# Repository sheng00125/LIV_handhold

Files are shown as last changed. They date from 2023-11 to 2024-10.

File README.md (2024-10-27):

# [LiDAR_Inertial_Visual_Handhold](https://zhuanlan.zhihu.com/p/670136001)

### News
* **`27 October 2024`:** Add modified livox_ros_driver2 with time sync support for Mid360.
* **`11 October 2024`:** Add support for other pixel formats besides RGB8 (e.g., BayerRG8, BayerRG12Packed).
* **`03 October 2024`:** Add ARM support, fix the camera driver startup and shutdown bug, remove the SerialNumber dependency, resolve the auto-exposure mode switching issue, and add a TriggerEnable interface to allow testing the camera without the PPS signal.
* **`15 July 2024`:** Fix the bug related to LiDAR (IMU) timestamp compensation in the `livox_ros_driver`, remove the dynamic library dependency from `mvs_ros_driver`, and enable this synchronization scheme to use the official `livox_sdk`.
* **`28 June 2024`:** Update reproduction videos and some important notes.
* **`27 May 2024`:** Fix a bug in the calculation of the synthetic GPRMC timestamp, which could cause timestamp rollback. Additionally, we add checksum verification for GPRMC.
* **`20 May 2024`:** According to Livox Avia's pin requirements, we convert PPS TTL level to RS485 level and supplement it with more detailed electronic connection and material list.

## 1. Introduction
This repository provides the **CAD files** (with suffix “\*.SLDPRT and \*.SLDASM”) for our handheld device, which can be opened and edited with [*Solidworks*](https://www.solidworks.com). All of the modules are suitable for printing with [*FDM (Fused Deposition Modeling)*](https://en.wikipedia.org/wiki/Fused_filament_fabrication). In addition, we have also open-sourced our **hardware synchronization scheme**, as well as the **STM32 source code** and **hardware wiring configuration** instructions.

<div align="center">
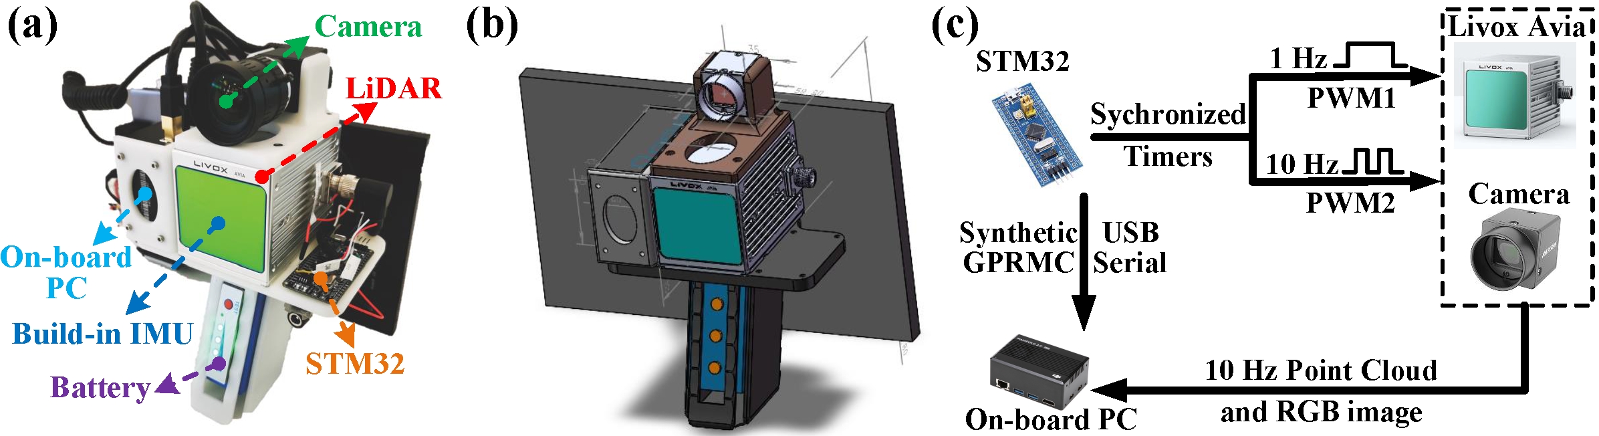
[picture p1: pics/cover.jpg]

</div>

## 2. Relevant guidance video 

Thanks to the Bilibili uploader [GundaSmart](https://space.bilibili.com/687639149?spm_id_from=333.788.0.0) for making a detailed reproduction video. Everyone can follow the video to reproduce it. His sensor configuration includes a MID360 and a Hikvision pinhole camera.

[FAST-LIVO Reproduction (Part 1)](https://www.bilibili.com/video/BV1T142197ci/?share_source=copy_web&vd_source=f77407286e8f0ee71b845d76498ada9d)

[FAST-LIVO Reproduction (Part 2)](https://www.bilibili.com/video/BV14T421X7m9/?share_source=copy_web&vd_source=f77407286e8f0ee71b845d76498ada9d)

[FAST-LIVO Reproduction (Part 3)](https://www.bilibili.com/video/BV16E42137ru/?share_source=copy_web&vd_source=f77407286e8f0ee71b845d76498ada9d)

[FAST-LIVO Reproduction (Part 4)](https://www.bilibili.com/video/BV1Yb421i7xK/?share_source=copy_web&vd_source=f77407286e8f0ee71b845d76498ada9d)

[FAST-LIVO Reproduction (Part 5)](https://www.bilibili.com/video/BV1Jz421b7px/?share_source=copy_web&vd_source=f77407286e8f0ee71b845d76498ada9d)

## 3. Guide to installation
### 3.1 Root directory

    ├── handhold_cad/ - CAD source files
    │   ├── ...
    ├── livox_ros_driver/ - Livox LiDAR ROS driver
    │   ├── ...
    ├── mvs_ros_pkg/ - Camera driver
    │   ├── ...
    └── stm32_timersync-open/ - Embedded engineering folder
    │   ├── USER/ - Main functionality folder
    │   ├── ...
    └── README.md - Project homepage document
    └── ...

### 3.2 Assembly instruction

The assembly instructions are demonstrated in the GIFs below. Each module is clearly labeled corresponding to the name of its STL file.

<p align="center">
  
  
</p>

### 3.3 Electronic connection
The guide for the electronic connections is presented as follows:

<table>
  <tr>
    <th>Livox AVIA LiDAR M12</th>
    <th>Peripheral Function</th>
    <th>Diagram</th>
  </tr>
  <tr>
    <td>PIN 1</td>
    <td>Power: +</td>
    <td rowspan="8" align="center">
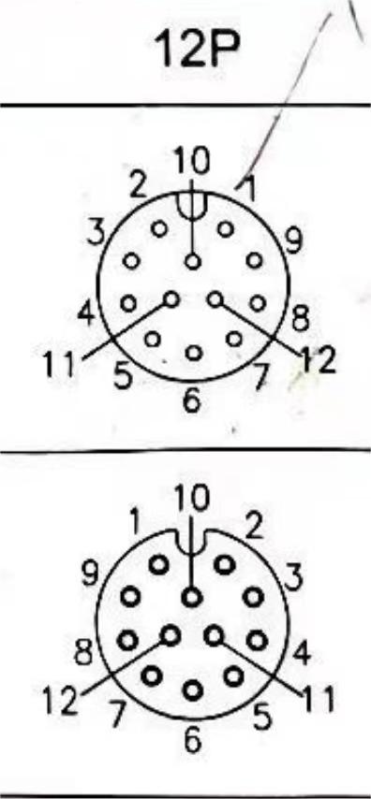
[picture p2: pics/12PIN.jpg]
      <br>
      <span style="display: block; text-align: center;">AVIA 12-Pin Interface, top: female bottom: male</span>
    </td>
  </tr>
  <tr>
    <td>PIN 2</td>
    <td>Ground</td>
  </tr>
  <tr>
    <td>PIN 7</td>
    <td>Ethernet: RX-</td>
  </tr>
  <tr>
    <td>PIN 6</td>
    <td>Ethernet: RX+</td>
  </tr>
  <tr>
    <td>PIN 5</td>
    <td>Ethernet: TX-</td>
  </tr>
  <tr>
    <td>PIN 4</td>
    <td>Ethernet: TX+</td>
  </tr>
  <tr>
    <td>PIN 11 (Sync-)</td>
    <td>RS485_Output B-</td>
  </tr>
  <tr>
    <td>PIN 12 (Sync+)</td>
    <td>RS485_Output A+</td>
  </tr>
</table>

<table>
  <tr>
    <th>MVS Camera 6PIN</th>
    <th>Name</th>
    <th>I/O Type</th>
    <th>Description</th>
    <th>Peripheral Function</th>
    <th>Diagram</th>
  </tr>
  <tr>
    <td>PIN 1</td>
    <td>DC_PWR</td>
    <td>--</td>
    <td>Power Supply</td>
    <td></td>
    <td rowspan="8" style="text-align: center;">
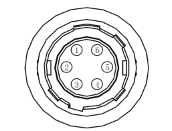
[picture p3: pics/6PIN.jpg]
      <br>
      <span style="display: block; text-align: center;">MVS Camera 6-Pin Interface</span>
    </td>
  </tr>
  <tr>
    <td>PIN 2</td>
    <td>OPTO_IN</td>
    <td>Line 0+</td>
    <td>Optical Isolation Input</td>
    <td>STM32 PA1</td>
  </tr>
  <tr>
    <td>PIN 3</td>
    <td>GPIO</td>
    <td>Line 2+</td>
    <td>General Purpose Input/Output</td>
    <td></td>
  </tr>
  <tr>
    <td>PIN 4</td>
    <td>OPTO_OUT</td>
    <td>Line 1+</td>
    <td>Optical Isolation Output</td>
    <td></td>
  </tr>
  <tr>
    <td>PIN 5</td>
    <td>OPTO_GND</td>
    <td>Line 0- / 1-</td>
    <td>Optical Isolation Ground</td>
    <td>STM32 GND</td>
  </tr>
  <tr>
    <td>PIN 6</td>
    <td>GND</td>
    <td>Line 2-</td>
    <td>Ground</td>
    <td></td>
  </tr>
</table>
<table>
  <tr>
    <th>STM32</th>
    <th>Peripheral Function</th>
  </tr>
  <tr>
    <td>PA1</td>
    <td>MVS camera PIN2 (OPTO_IN)</td>
  </tr>
  <tr>
    <td>PB5</td>
    <td>RS485_Input (TXD)</td>
  </tr>
  <tr>
    <td>PA9</td>
    <td>TTL2USB (RXD)</td>
  </tr>
  <tr>
    <td>VCC</td>
    <td>RS485_Input (VCC) | TTL2USB (VCC)</td>
  </tr>
  <tr>
    <td>GND</td>
    <td>RS485_Input (GND) | TTL2USB (GND) | MVS camera PIN5 (GND)</td>
  </tr>
</table>

<table>
  <tr>
    <th>RS485</th>
    <th>Peripheral Function</th>
  </tr>
  <tr>
    <td>RS485_Output A+</td>
    <td>LiDAR M12 PIN12 (Sync+)</td>
  </tr>
  <tr>
    <td>RS485_Output B-</td>
    <td>LiDAR M12 PIN11 (Sync-)</td>
  </tr>
  <tr>
    <td>RS485_Output (GND)</td>
    <td>LiDAR M12 PIN2 (GND)</td>
  </tr>
</table>

**🔴🔥 IMPORTANT:**
* **STM32 PB5 (PPS signal) is converted from TTL to RS-485, resulting in RS485_Output A+ and RS485_Output B-;**
* **STM32 TXD (GPRMC) is converted from TTL to USB and sent to the PC;** 
* **If you are using the Mid360, you can directly connect STM32 PB5 to LiDAR M12 pps interface;**
* **Before you `roslaunch livox_ros_driver livox_lidar_msg.launch`, you can use `sudo chmod a+rw /dev/ttyUSB0` grant permissions to the USB serial port;**
* **The default connection method in this repository directly connects to M12 without using the Livox converter. If you use the converter, you can connect STM32 PB5 (PPS signal) to the Livox converter Sync Port without converting TTL to 485 level. Refer to [Issue 19](https://github.com/sheng00125/LIV_handhold/issues/19) for details.**

## 4. How to run the driver
```bash
roslaunch mvs_ros_pkg mvs_camera_trigger.launch
roslaunch livox_ros_driver livox_lidar_msg.launch
rosbag record /livox/lidar /livox/imu left_camera/image
```

## 5. Main material lists (only for reference)
| Item  | Pics  | Purchasing list  |
| :---: | :---: | :---: |
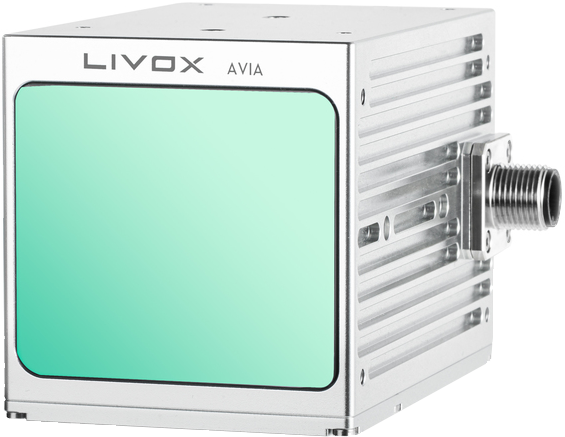
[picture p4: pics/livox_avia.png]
| Livox Avia LiDAR  |  | [Livox Avia](https://store.dji.com/hk-en/product/livox-avia) |
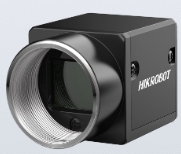
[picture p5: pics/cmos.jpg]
| CMOS |  | [MV-CA013-21UC ](https://www.hikrobotics.com/en/machinevision/productdetail?id=1314&pageNumber=1&pageSize=50) |
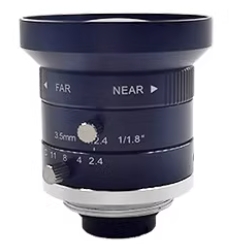
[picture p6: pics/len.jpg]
| Camera Len |  | [ MVL-HF0628M-6MPE](https://m.tb.cn/h.gXmtLRX2UYzGDzH?tk=hIS7WGPOY0y) |
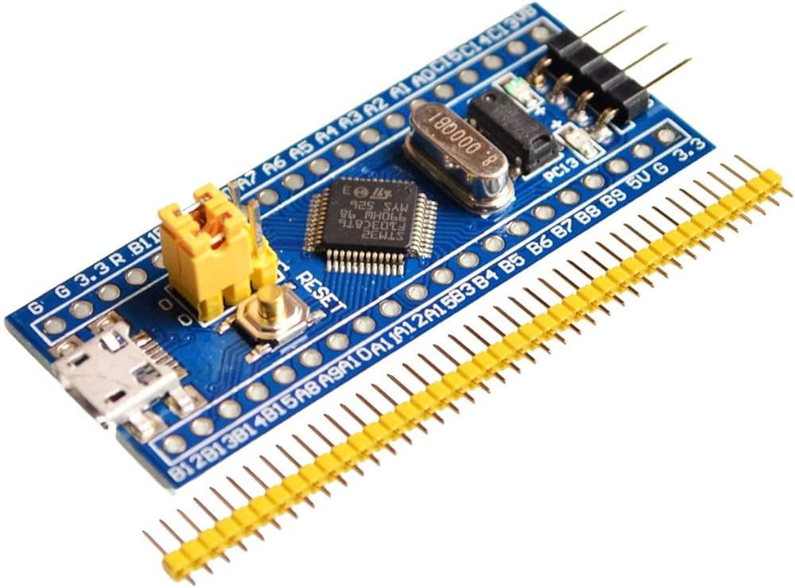
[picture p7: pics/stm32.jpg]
| STM32 |  | [STM32F103C8T6](https://m.tb.cn/h.ggkS9Kp?tk=orRfWz6M784) |
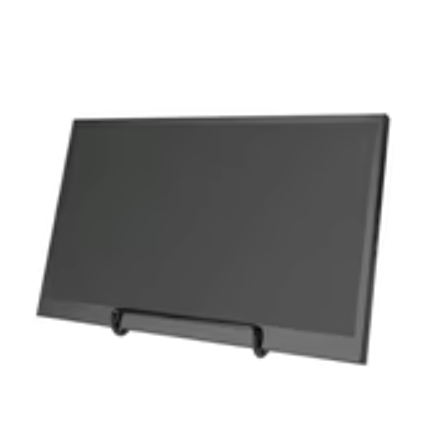
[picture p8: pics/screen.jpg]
| Screen |  | [IPS Screen 10''](https://m.tb.cn/h.ggkhQ7e?tk=LntBWz6mHDL) |
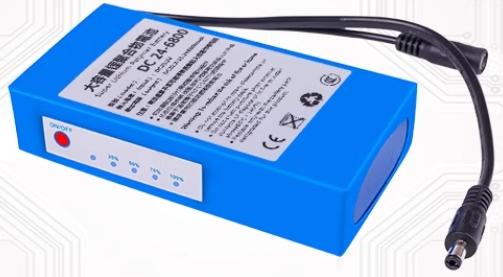
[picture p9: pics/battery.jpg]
| Battery |  | [4800mah](https://m.tb.cn/h.g5vJI7a?tk=ofKdWz6OYQm) |
| TTL to USB |  | [TTL to USB](https://m.tb.cn/h.gWzMxzBSkhSqkH3?tk=N1j3WEzIP9u) |
| TTL to 485 |  | [TTL to 485](https://m.tb.cn/h.g3SEkso?tk=eER4WEzFYmP) |

## 6. License
The source code is released under [GPLv3](http://www.gnu.org/licenses/) license. 

If you use any code of this repo in your academic research, it will be **very appreciated** if you can cite any of our following papers:

```
[1] Zheng, Chunran, et al. "FAST-LIVO2: Fast, Direct LiDAR-Inertial-Visual Odometry." 
[2] Zheng, Chunran, et al. "FAST-LIVO: Fast and Tightly-coupled Sparse-Direct LiDAR-Inertial-Visual Odometry." 
[3] Hong, Sheng, et al. "Rollvox: real-time and high-quality LiDAR colorization with rolling shutter camera." 
```

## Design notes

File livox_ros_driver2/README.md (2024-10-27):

# Update

Added the time synchronization function

# Livox ROS Driver 2

Livox ROS Driver 2 is the 2nd-generation driver package used to connect LiDAR products produced by Livox, applicable for ROS (noetic recommended) and ROS2 (foxy or humble recommended).

  **Note :**

  As a debugging tool, Livox ROS Driver is not recommended for mass production but limited to test scenarios. You should optimize the code based on the original source to meet your various needs.

## 1. Preparation

### 1.1 OS requirements

  * Ubuntu 18.04 for ROS Melodic;
  * Ubuntu 20.04 for ROS Noetic and ROS2 Foxy;
  * Ubuntu 22.04 for ROS2 Humble;

  **Tips:**

  Colcon is a build tool used in ROS2.

  How to install colcon: [Colcon installation instructions](https://docs.ros.org/en/foxy/Tutorials/Beginner-Client-Libraries/Colcon-Tutorial.html)

### 1.2 Install ROS & ROS2

For ROS Melodic installation, please refer to:
[ROS Melodic installation instructions](https://wiki.ros.org/melodic/Installation)

For ROS Noetic installation, please refer to:
[ROS Noetic installation instructions](https://wiki.ros.org/noetic/Installation)

For ROS2 Foxy installation, please refer to:
[ROS Foxy installation instructions](https://docs.ros.org/en/foxy/Installation/Ubuntu-Install-Debians.html)

For ROS2 Humble installation, please refer to:
[ROS Humble installation instructions](https://docs.ros.org/en/humble/Installation/Ubuntu-Install-Debians.html)

Desktop-Full installation is recommend.

## 2. Build & Run Livox ROS Driver 2

### 2.1 Clone Livox ROS Driver 2 source code:

```shell
git clone https://github.com/Livox-SDK/livox_ros_driver2.git ws_livox/src/livox_ros_driver2
```

  **Note :**

  Be sure to clone the source code in a '[work_space]/src/' folder (as shown above), otherwise compilation errors will occur due to the compilation tool restriction.

### 2.2 Build & install the Livox-SDK2

  **Note :**

  Please follow the guidance of installation in the [Livox-SDK2/README.md](https://github.com/Livox-SDK/Livox-SDK2/blob/master/README.md)

### 2.3 Build the Livox ROS Driver 2:

#### For ROS (take Noetic as an example):
```shell
source /opt/ros/noetic/setup.sh
./build.sh ROS1
```

#### For ROS2 Foxy:
```shell
source /opt/ros/foxy/setup.sh
./build.sh ROS2
```

#### For ROS2 Humble:
```shell
source /opt/ros/humble/setup.sh
./build.sh humble
```

### 2.4 Run Livox ROS Driver 2:

#### For ROS:

```shell
source ../../devel/setup.sh
roslaunch livox_ros_driver2 [launch file]
```

in which,  

* **livox_ros_driver2** : is the ROS package name of Livox ROS Driver 2;
* **[launch file]** : is the ROS launch file you want to use; the 'launch_ROS1' folder contains several launch samples for your reference;  

An rviz launch example for HAP LiDAR would be:

```shell
roslaunch livox_ros_driver2 rviz_HAP.launch
```

#### For ROS2:
```shell
source ../../install/setup.sh
ros2 launch livox_ros_driver2 [launch file]
```

in which,  

* **[launch file]** : is the ROS2 launch file you want to use; the 'launch_ROS2' folder contains several launch samples for your reference.

A rviz launch example for HAP LiDAR would be:

```shell
ros2 launch livox_ros_driver2 rviz_HAP_launch.py
```

## 3. Launch file and livox_ros_driver2 internal parameter configuration instructions

### 3.1 Launch file configuration instructions

Launch files of ROS are in the "ws_livox/src/livox_ros_driver2/launch_ROS1" directory and launch files of ROS2 are in the "ws_livox/src/livox_ros_driver2/launch_ROS2" directory. Different launch files have different configuration parameter values and are used in different scenarios:

| launch file name | Description |
| --- | --- |
| rviz_HAP.launch | Connect to HAP LiDAR device<br>Publish pointcloud2 format  data<br>Autoload rviz |
| msg_HAP.launch | Connect to HAP LiDAR device<br>Publish livox customized pointcloud data|
| rviz_MID360.launch | Connect to MID360 LiDAR device<br>Publish pointcloud2 format data <br>Autoload rviz|
| msg_MID360.launch | Connect to MID360 LiDAR device<br>Publish livox customized pointcloud data |
| rviz_mixed.launch | Connect to HAP and MID360 LiDAR device<br>Publish pointcloud2 format data <br>Autoload rviz|
| msg_mixed.launch | Connect to HAP and MID360 LiDAR device<br>Publish livox customized pointcloud data |

### 3.2 Livox ros driver 2 internal main parameter configuration instructions

All internal parameters of Livox_ros_driver2 are in the launch file. Below are detailed descriptions of the three commonly used parameters :

| Parameter | Detailed description | Default |
| --- | --- | --- |
| publish_freq | Set the frequency of point cloud publish <br>Floating-point data type, recommended values 5.0, 10.0, 20.0, 50.0, etc. The maximum publish frequency is 100.0 Hz.| 10.0 |
| multi_topic  | If the LiDAR device has an independent topic to publish pointcloud data<br>0 -- All LiDAR devices use the same topic to publish pointcloud data<br>1 -- Each LiDAR device has its own topic to publish point cloud data | 0 |
| xfer_format  | Set pointcloud format<br>0 -- Livox pointcloud2(PointXYZRTLT) pointcloud format<br>1 -- Livox customized pointcloud format<br>2 -- Standard pointcloud2 (pcl :: PointXYZI) pointcloud format in the PCL library (just for ROS) | 0 |

  **Note :**

  Other parameters not mentioned in this table are not suggested to be changed unless fully understood.

&ensp;&ensp;&ensp;&ensp;***Livox_ros_driver2 pointcloud data detailed description :***

1. Livox pointcloud2 (PointXYZRTLT) point cloud format, as follows :

```c
float32 x               # X axis, unit:m
float32 y               # Y axis, unit:m
float32 z               # Z axis, unit:m
float32 intensity       # the value is reflectivity, 0.0~255.0
uint8   tag             # livox tag
uint8   line            # laser number in lidar
float64 timestamp       # Timestamp of point
```
  **Note :**

  The number of points in the frame may be different, but each point provides a timestamp.

2. Livox customized data package format, as follows :

```c
std_msgs/Header header     # ROS standard message header
uint64          timebase   # The time of first point
uint32          point_num  # Total number of pointclouds
uint8           lidar_id   # Lidar device id number
uint8[3]        rsvd       # Reserved use
CustomPoint[]   points     # Pointcloud data
```

&ensp;&ensp;&ensp;&ensp;Customized Point Cloud (CustomPoint) format in the above customized data package :

```c
uint32  offset_time     # offset time relative to the base time
float32 x               # X axis, unit:m
float32 y               # Y axis, unit:m
float32 z               # Z axis, unit:m
uint8   reflectivity    # reflectivity, 0~255
uint8   tag             # livox tag
uint8   line            # laser number in lidar
```

3. The standard pointcloud2 (pcl :: PointXYZI) format in the PCL library (only ROS can publish):

&ensp;&ensp;&ensp;&ensp;Please refer to the pcl :: PointXYZI data structure in the point_types.hpp file of the PCL library.

## 4. LiDAR config

LiDAR Configurations (such as ip, port, data type... etc.) can be set via a json-style config file. Config files for single HAP, Mid360 and mixed-LiDARs are in the "config" folder. The parameter naming *'user_config_path'* in launch files indicates such json file path.

1. Follow is a configuration example for HAP LiDAR (located in config/HAP_config.json):

```json
{
  "lidar_summary_info" : {
    "lidar_type": 8  # protocol type index, please don't revise this value
  },
  "HAP": {
    "device_type" : "HAP",
    "lidar_ipaddr": "",
    "lidar_net_info" : {
      "cmd_data_port": 56000,  # command port
      "push_msg_port": 0,
      "point_data_port": 57000,
      "imu_data_port": 58000,
      "log_data_port": 59000
    },
    "host_net_info" : {
      "cmd_data_ip" : "192.168.1.5",  # host ip (it can be revised)
      "cmd_data_port": 56000,
      "push_msg_ip": "",
      "push_msg_port": 0,
      "point_data_ip": "192.168.1.5",  # host ip
      "point_data_port": 57000,
      "imu_data_ip" : "192.168.1.5",  # host ip
      "imu_data_port": 58000,
      "log_data_ip" : "",
      "log_data_port": 59000
    }
  },
  "lidar_configs" : [
    {
      "ip" : "192.168.1.100",  # ip of the LiDAR you want to config
      "pcl_data_type" : 1,
      "pattern_mode" : 0,
      "blind_spot_set" : 50,
      "extrinsic_parameter" : {
        "roll": 0.0,
        "pitch": 0.0,
        "yaw": 0.0,
        "x": 0,
        "y": 0,
        "z": 0
      }
    }
  ]
}
```

The parameter attributes in the above json file are described in the following table :

**LiDAR configuration parameter**
| Parameter | Type | Description | Default |
| :--- | --- | --- | --- |
| ip | String  | Ip of the LiDAR you want to config | 192.168.1.100 |
| pcl_data_type | Int | Choose the resolution of the point cloud data to send<br>1 -- Cartesian coordinate data (32 bits)<br>2 -- Cartesian coordinate data (16 bits) <br>3 --Spherical coordinate data| 1 |
| pattern_mode | Int | Space scan pattern<br>0 -- non-repeating scanning pattern mode<br>1 -- repeating scanning pattern mode <br>2 -- repeating scanning pattern mode (low scanning rate) | 0 |
| blind_spot_set (Only for HAP LiDAR) | Int | Set blind spot<br>Range from 50 cm to 200 cm | 50 |
| extrinsic_parameter | | Set extrinsic parameter<br> The data types of "roll" "picth" "yaw" are float <br>  The data types of "x" "y" "z" are int<br> |

For more infomation about the HAP config, please refer to:
[HAP Config File Description](https://github.com/Livox-SDK/Livox-SDK2/wiki/hap-config-file-description)

2. When connecting multiple LiDARs, add objects corresponding to different LiDARs to the "lidar_configs" array. Examples of mixed-LiDARs config file contents are as follows :

```json
{
  "lidar_summary_info" : {
    "lidar_type": 8  # protocol type index, please don't revise this value
  },
  "HAP": {
    "lidar_net_info" : {  # HAP ports, please don't revise these values
      "cmd_data_port": 56000,  # HAP command port
      "push_msg_port": 0,
      "point_data_port": 57000,
      "imu_data_port": 58000,
      "log_data_port": 59000
    },
    "host_net_info" : {
      "cmd_data_ip" : "192.168.1.5",  # host ip
      "cmd_data_port": 56000,
      "push_msg_ip": "",
      "push_msg_port": 0,
      "point_data_ip": "192.168.1.5",  # host ip
      "point_data_port": 57000,
      "imu_data_ip" : "192.168.1.5",  # host ip
      "imu_data_port": 58000,
      "log_data_ip" : "",
      "log_data_port": 59000
    }
  },
  "MID360": {
    "lidar_net_info" : {  # Mid360 ports, please don't revise these values
      "cmd_data_port": 56100,  # Mid360 command port
      "push_msg_port": 56200,
      "point_data_port": 56300,
      "imu_data_port": 56400,
      "log_data_port": 56500
    },
    "host_net_info" : {
      "cmd_data_ip" : "192.168.1.5",  # host ip
      "cmd_data_port": 56101,
      "push_msg_ip": "192.168.1.5",  # host ip
      "push_msg_port": 56201,
      "point_data_ip": "192.168.1.5",  # host ip
      "point_data_port": 56301,
      "imu_data_ip" : "192.168.1.5",  # host ip
      "imu_data_port": 56401,
      "log_data_ip" : "",
      "log_data_port": 56501
    }
  },
  "lidar_configs" : [
    {
      "ip" : "192.168.1.100",  # ip of the HAP you want to config
      "pcl_data_type" : 1,
      "pattern_mode" : 0,
      "blind_spot_set" : 50,
      "extrinsic_parameter" : {
        "roll": 0.0,
        "pitch": 0.0,
        "yaw": 0.0,
        "x": 0,
        "y": 0,
        "z": 0
      }
    },
    {
      "ip" : "192.168.1.12",  # ip of the Mid360 you want to config
      "pcl_data_type" : 1,
      "pattern_mode" : 0,
      "extrinsic_parameter" : {
        "roll": 0.0,
        "pitch": 0.0,
        "yaw": 0.0,
        "x": 0,
        "y": 0,
        "z": 0
      }
    }
  ]
}
```

## 5. Supported LiDAR list

* HAP
* Mid360
* (more types are comming soon...)

## 6. FAQ

### 6.1 launch with "livox_lidar_rviz_HAP.launch" but no point cloud display on the grid?

Please check the "Global Options - Fixed Frame" field in the RViz "Display" pannel. Set the field value to "livox_frame" and check the "PointCloud2" option in the pannel.

### 6.2 launch with command "ros2 launch livox_lidar_rviz_HAP_launch.py" but cannot open shared object file "liblivox_sdk_shared.so" ?

Please add '/usr/local/lib' to the env LD_LIBRARY_PATH.

* If you want to add to current terminal:

  ```shell
  export LD_LIBRARY_PATH=${LD_LIBRARY_PATH}:/usr/local/lib
  ```

* If you want to add to current user:

  ```shell
  vim ~/.bashrc
  export LD_LIBRARY_PATH=${LD_LIBRARY_PATH}:/usr/local/lib
  source ~/.bashrc
  ```

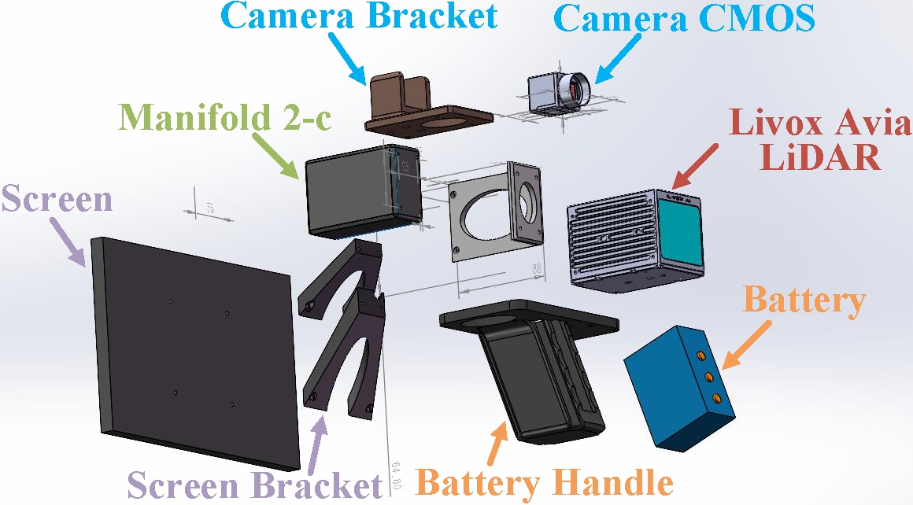
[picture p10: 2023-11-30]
pics/stl.jpg

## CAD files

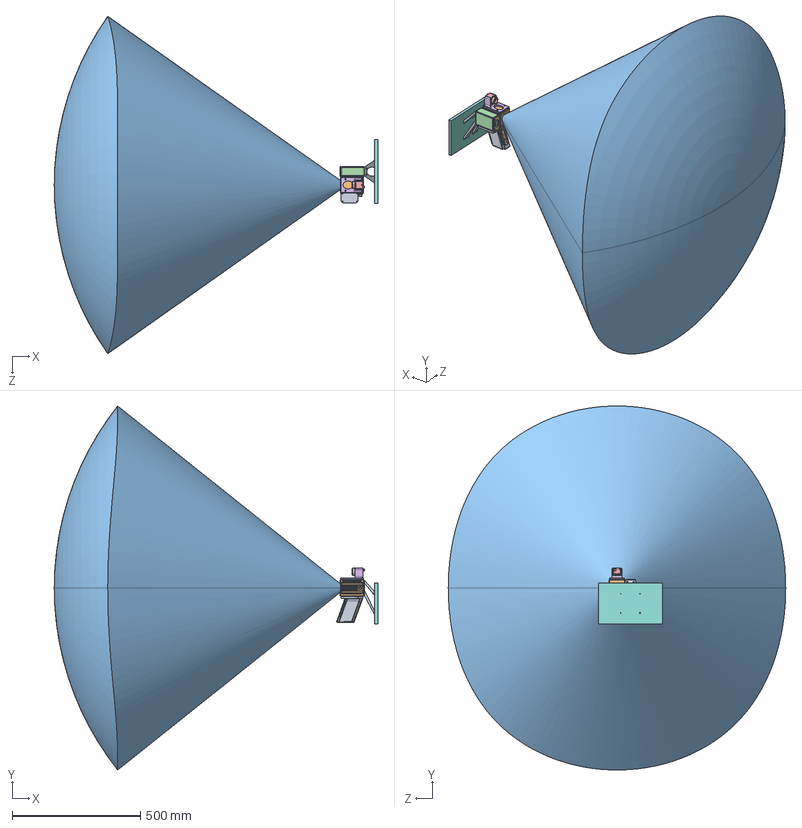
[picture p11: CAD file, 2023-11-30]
handhold_cad/LIVO.SLDASM
1262.6 x 1420.3 x 1316.9 mm
LIVOX_AVIA.stp
DJI_manifold2
FL2-020-R0
T_cam_livox
main_livox
screen
handhold
fix
POWER

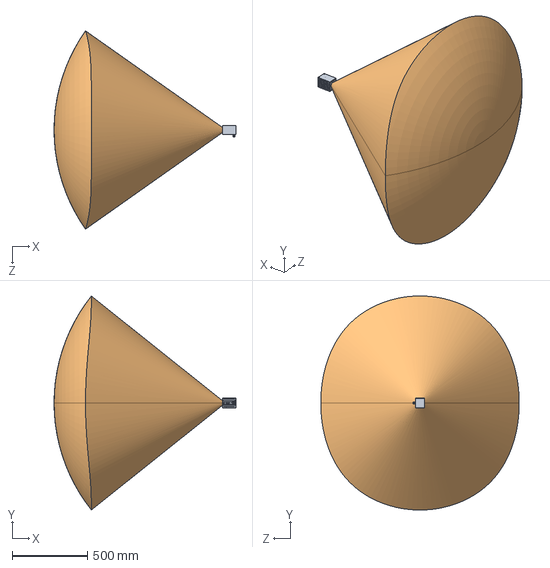
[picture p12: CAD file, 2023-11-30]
handhold_cad/AVIA.SLDASM
1207.6 x 1420.3 x 1316.9 mm

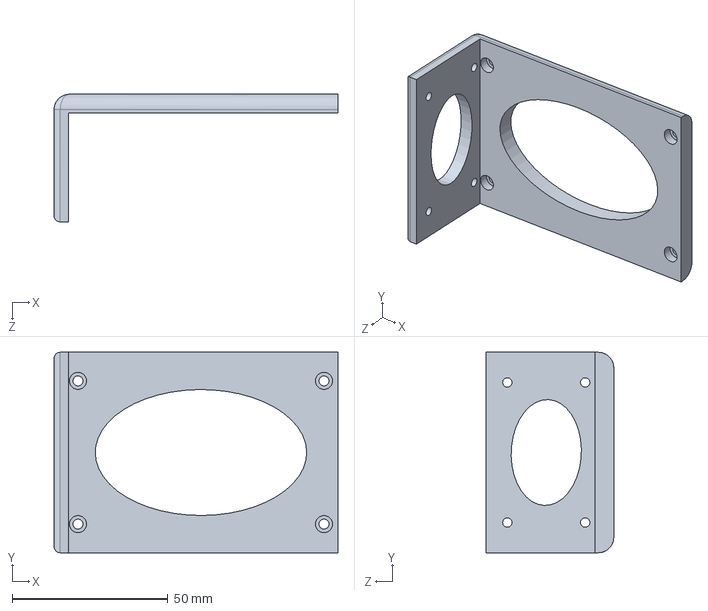
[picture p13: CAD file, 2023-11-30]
handhold_cad/main_livox.SLDPRT
91.2 x 64.4 x 41.0 mm

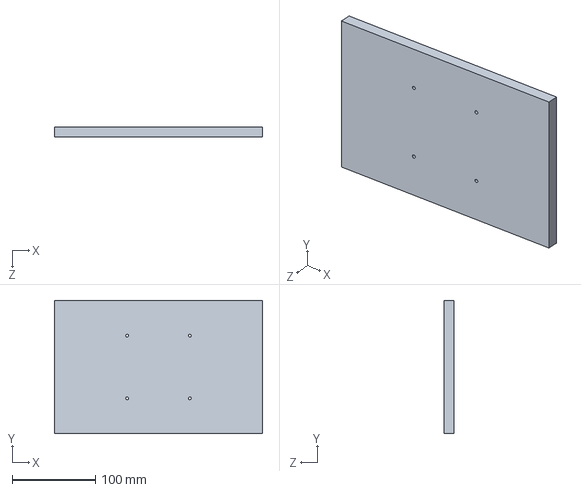
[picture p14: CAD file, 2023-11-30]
handhold_cad/screen.SLDPRT
250.0 x 160.0 x 12.0 mm

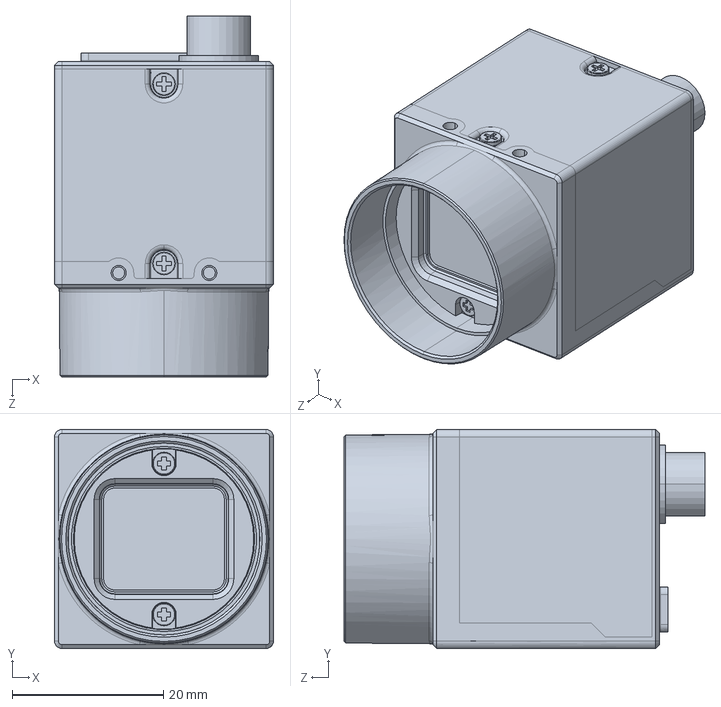
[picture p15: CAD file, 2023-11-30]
handhold_cad/FL2-020-R0.SLDPRT
29.0 x 29.0 x 47.8 mm

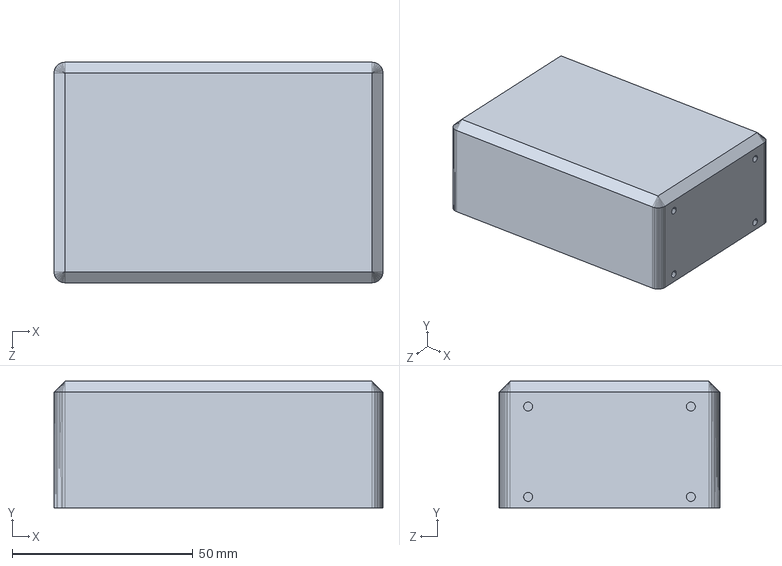
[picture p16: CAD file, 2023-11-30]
handhold_cad/DJI_manifold2.SLDPRT
91.0 x 35.0 x 61.0 mm

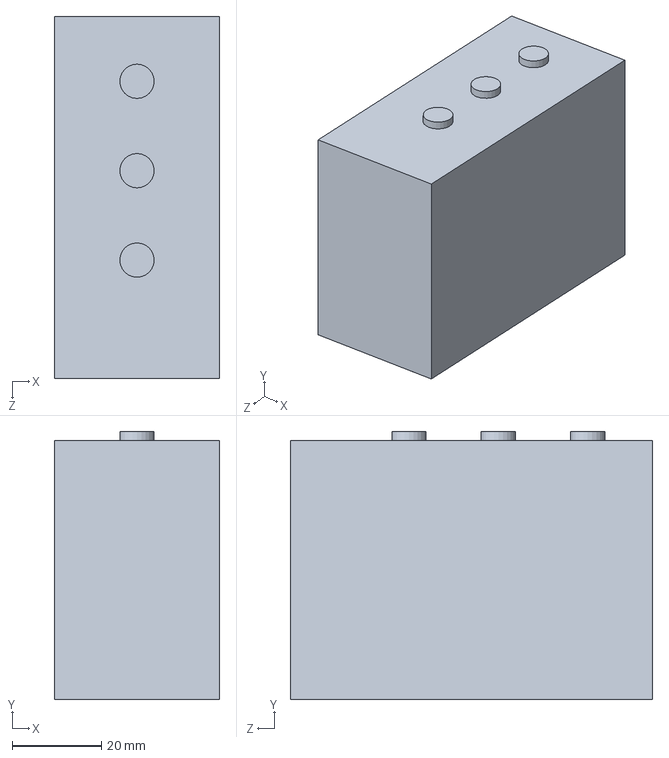
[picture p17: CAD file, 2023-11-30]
handhold_cad/POWER.SLDPRT
37.0 x 60.0 x 81.0 mm

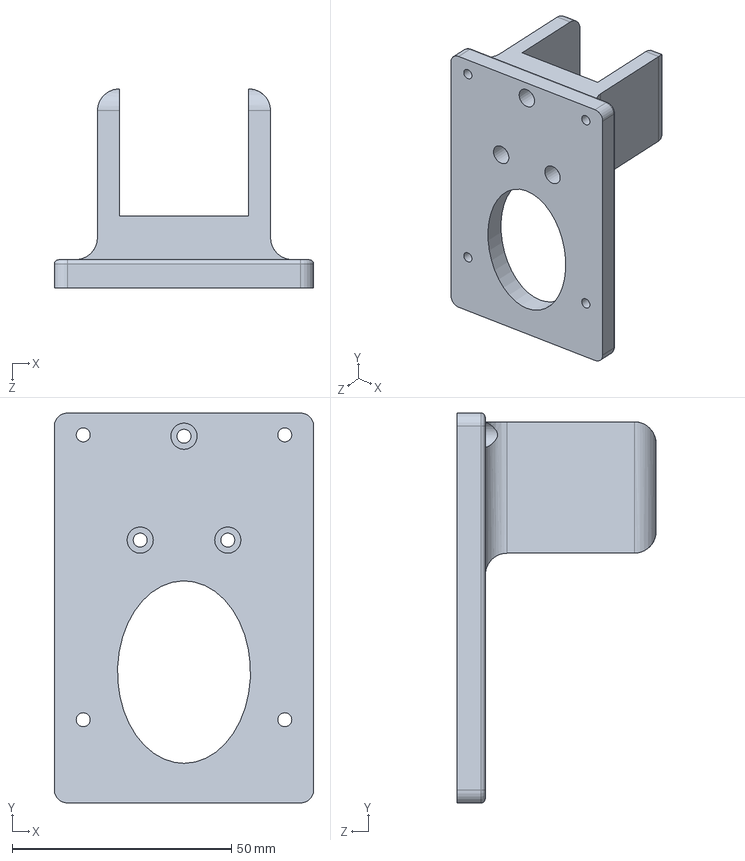
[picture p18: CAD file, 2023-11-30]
handhold_cad/T_cam_livox.SLDPRT
59.2 x 89.0 x 45.5 mm

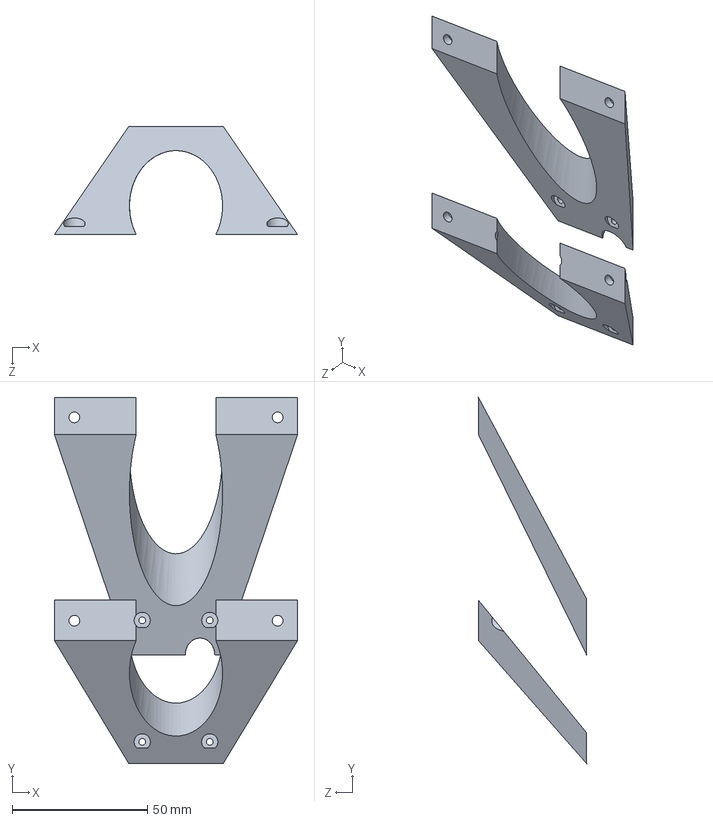
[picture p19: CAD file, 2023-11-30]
handhold_cad/fix.SLDPRT
90.0 x 135.5 x 40.0 mm

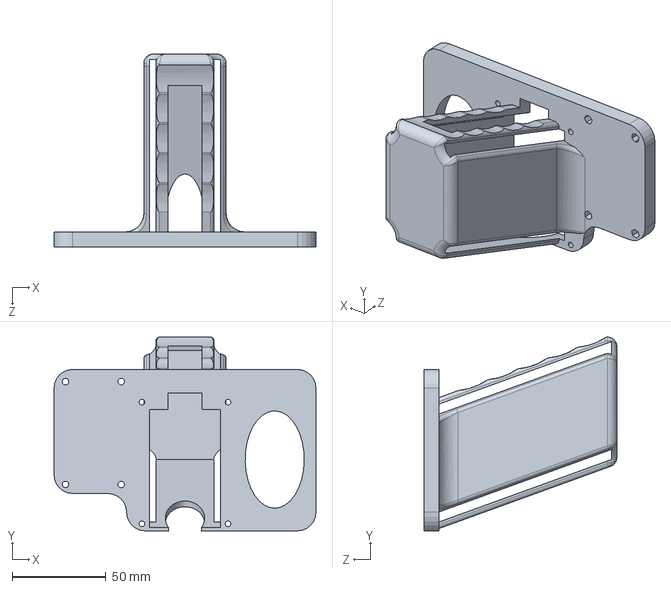
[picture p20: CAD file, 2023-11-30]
handhold_cad/handhold.SLDPRT
140.0 x 103.6 x 103.0 mm

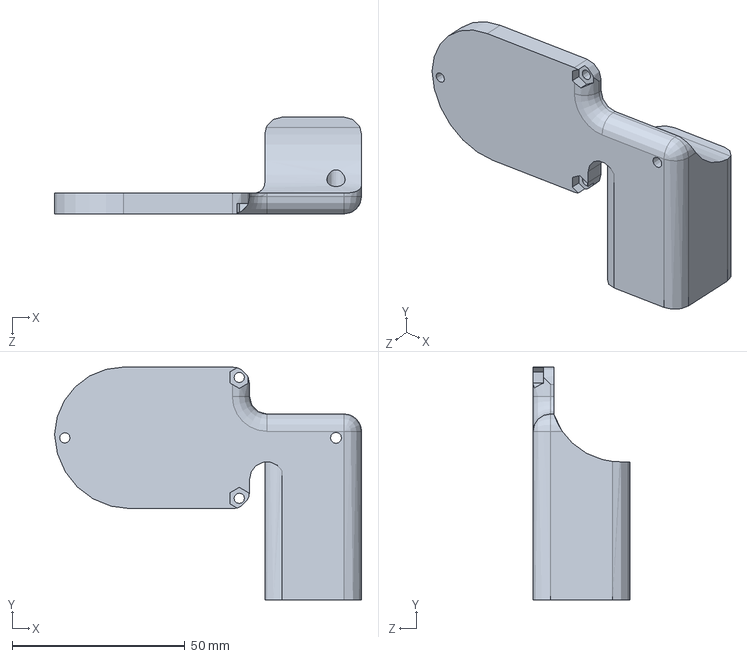
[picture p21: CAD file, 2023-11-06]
handhold_cad/fix_imu.SLDPRT
88.9 x 67.4 x 28.0 mm

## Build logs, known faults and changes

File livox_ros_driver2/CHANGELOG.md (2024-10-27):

# Changelog

All notable changes to this project will be documented in this file.

## [1.2.4]
### Fixed
- Optimize framing performance

## [1.2.3]
### Fixed
- Optimize framing logic and reduce CPU usage
- Fixed some known issues

## [1.2.1]
### Fixed
- Fix offset time error regarding CustomMsg format message publishment.

## [1.2.0]
### Added
- Revise the frame segmentation logic.
- (Notice!!!) Add Timestamp to each point in Livox pointcloud2 (PointXYZRTLT) format. The PointXYZRTL format has been updated to PointXYZRTLT format. Compatibility needs to be considered.
### Fixed
- Improve support for gPTP and GPS synchronizations.

--- 
## [1.1.3]
### Fixed
- Improve performance when running in ROS2 Humble.

--- 
## [1.1.2]
### Changed
- Change publish frequency range to [0.5Hz, 10 Hz].
### Fixed
- Fix a high CPU-usage problem.

--- 
## [1.1.1]
### Added
- Offer valid line-number info in the point cloud data of MID-360 Lidar.
- Enable IMU by default.
### Changed
- Update the README slightly.

--- 
## [1.0.0]
### Added
- Support Mid-360 Lidar.
- Support for Ubuntu 22.04 ROS2 humble.
- Support multi-topic fuction, the suffix of the topic name corresponds to the ip address of each Lidar. 
### Changed
- Remove the embedded SDK.
- Constraint: Livox ROS Driver 2 for ROS2 does not support message passing with PCL native data types.
### Fixed
- Fix IMU packet loss.
- Fix some conflicts with livox ros driver.
- Fixed HAP Lidar publishing PointCloud2 and CustomMsg format point clouds with no line number.

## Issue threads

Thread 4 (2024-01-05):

Hardware synchronization scheme的理解

Alex-Beh, 2024-01-05:
下面这个if else case的return是否倒反了阿？
https://github.com/sheng00125/LIV_handhold/blob/658214b67c4b2c293c1c22ef47291861aa2ddec4/livox_ros_driver/timesync/timesync.h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

https://github.com/sheng00125/LIV_handhold/blob/658214b67c4b2c293c1c22ef47291861aa2ddec4/livox_ros_driver/livox_ros_driver/lds_lidar.cpp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

还有能否写个summary关于整个hardware synchronization scheme? 从右图能理解是stm出生成一个GPRMC的数据包然后雷达和相机会读取该数据然后解析为时间段，那该时间和Onboard PC上的时间是否就不一样的？
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

xuankuzcr, 2024-01-27:
对和电脑时间戳是不一样的，时间戳是stm32产生的一个假的时间戳

Closed 2024-05-27.

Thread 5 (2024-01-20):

如何测试是否真的同步了

Low-Keyy, 2024-01-20:

Low-Keyy, 2024-01-20:
有什么好的观测方法吗

xuankuzcr, 2024-01-27:
可以试着把点云投影到图像或者图像上色到点云

Low-Keyy, 2024-01-28:
> 可以试着把点云投影到图像或者图像上色到点云

谢谢

hopenessQAQ, 2024-07-08:
> 可以试着把点云投影到图像或者图像上色到点云

您好，使用rqt_bag测试是否同步可以么？

xuankuzcr, 2024-07-10:
不可以，`rqt_bag` 显示的是消息在bag文件中被记录的系统时间，这与消息本身的时间戳（通常存储在消息的header字段中）是不同的。另外就算header的时间戳能对上，也不一定是同步好的数据。

> 可以试着把点云投影到图像或者图像上色到点云

这个是最有效的方法。

Closed 2024-01-28.

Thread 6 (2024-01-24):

Request for On-board PC Model Details

DreamWaterFound, 2024-01-24:
Hello!

Could you please provide the specific model and specifications of the On-board PC used in the LiDAR_Inertial_Visual_Handheld device? The information will be greatly beneficial for those of us looking to replicate or understand your design better.

Thanks!

xuankuzcr, 2024-01-27:
Hi, Guoqing
Thanks for your interest. Our pc model is Manifold 2-c.

DreamWaterFound, 2024-01-28:
It is helpful to me, thanks for your reply!  👍

Closed 2024-01-28.

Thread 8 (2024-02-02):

avia的电压是10-15V

BG2CRW, 2024-02-02:
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
手册中写电源是10-15V（不接converter2.0），看您接线好像直接接到24V电池上了,请问您实际上是否加了DCDC

xuankuzcr, 2024-02-02:
加了 你就买个宽电压转12v就行

BG2CRW, 2024-02-22:
另外11，12脚是485A和485B，不需要接个485转换芯片，直接接stm32就可以吗

sheng00125, 2024-02-24:
我直接接STM32的TTL电平的引脚，没什么问题。

Closed 2024-05-27.

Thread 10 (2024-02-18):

请问这套设备的硬同步适用LIVOX_Horizon雷达与海康相机吗？

liunao123, 2024-02-18:
您好，我现在将雷达换成LIVOX_Horizon，相机还是海康，测试发现二者的时间戳是变成一样的了，但是底层对于雷达时间的改写一直不对劲，测试发现：雷达的sdk接受到了GPRMC消息，最后调用底层的LidarSetUtcSyncTime接口，这个接口虽然返回了0（也就是成功），但是其雷达的时间戳依然是从上电时刻起算的，GPRMC内的时间戳并没有赋值过去，请问您有碰到这种情况吗？您感觉有什么可能的原因呢？热切期待你的回复，谢谢 >_<

85256638, 2024-07-26:
大佬怎么结局了啊？希望关闭问题之前，把答案也分享下来。

xuankuzcr, 2024-07-26:
在我们之前[Camvox](https://github.com/ISEE-Technology/CamVox)的工作里，这个同步方案也是没问题的。建议重新pull一下最新的修复bug后的stm32固件和LiDAR driver，再看看是否能读取到GPRMC的时间戳。

liunao123, 2024-07-26:
@xuankuzcr 谢谢您的回复，我测试发现之前串口发送的GPRMC没有严格与官方给的一致，导致异常。更改其格式就正常了。
现在还有一个问题，不知道什么原因：GPRMC信息，串口单独去读，基本正常，但是livox的sdk去解析GPRMC信息的时候，会偶尔出现类似堵塞的情况，需要解析的内容会包含很多个GPRMC信息，最新的一帧是在最前面，所以我加了一个只读取最前面的GPRMC信息的一个逻辑，也就正常使用了。
您说的更新固件我找时间去试一下。有结果我反馈到这，谢谢您（握手).
@85256638 您看一下我这个，看能不能解决您的问题。

Closed 2024-03-11.

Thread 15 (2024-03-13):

AVIA 雷达的pps sync变成Sync Abnormal

liunao123, 2024-03-13:
你好，最近我在测试AVIA与海康相机的同步效果，我也是用stm32发送的模拟GPRMC数据，串口数据的收发都正常的。
现在碰到2个问题：
1、每次上电第一次启动livox_ros_driver的时候，雷达的时间戳是没有被赋值成GPRMC里面的时间的，并且驱动会一直报错：时间回退了，我打印了时间戳，发现相邻两个雷达时间也不是连续的（现在的timestamp不是下一次的last_timestamp），imu数据也是这样。但是我关闭程序再启动，发现此时的 GPRMC时间戳赋值到了 雷达数据里，相邻数据的时间戳也连续了。
2、每次上电的时候，livox_viewer查看同步状态是pps sync， 而一旦运行了livox_ros_driver，同步状态就会变成Sync Abnormal，然后就一直保持Sync Abnormal，直到断电重启才会恢复成pps sync，请问可能是哪方面的原因呢？
十分期待你的回复，谢谢-_-

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

sheng00125, 2024-04-01:
更新一下Avia的固件

xuankuzcr, 2024-05-27:
可以测试下新的stm32固件，修复了些bug。

jizhou626, 2024-11-15:
你好，我也出现了同样的问题，请问一下您是怎么解决的

dujunjie90, 2025-09-20:
你好我也遇到了你一样的问题想问你是怎么解决的

Closed 2024-06-28.

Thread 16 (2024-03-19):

手持设备硬件设计方案

MisEty, 2024-03-19:
您好，感谢您开源如此优秀的工作来推动社区发展！现在我希望能搭建类似的LIV手持扫描设备复现FAST-LIVO，但对于硬件组成仍然有一些疑问：
1. 硬件系统的具体工作流程是怎样的？我的个人理解是STM32给雷达和相机分别发送同步的脉冲信号，雷达和相机接收信号后以同步的频率进行扫描，将结果传输给计算机执行后续SLAM任务
2. 设备中的on-board PC是必要的吗？是不是所有计算都在DJI manifold-2c上执行？能否使用笔记本电脑等算力更强的设备替代？
3. 是否一定要集成ros系统？我注意到所有的驱动都是集成到ros中的，FAST-LIVO也是以ros包的形式发布的，能否类似ElasticFusion那样作为不依赖ros的视线？
4. STM32在这个系统中是必要的吗，如果只是控制脉冲同步的话能否采用更简单的板子？
5. 如果使用其他的硬件，比如其他的相机型号，能否继续采用这个设计方案？

MisEty, 2024-04-16:
> 1.这个需要看代码去理解，具体原理也可以参考FAST-LIVO。【[https://arxiv.org/abs/2203.00893】](https://arxiv.org/abs/2203.00893%E3%80%91) 2.可以用笔记本替代mainfold，最开始我也是拿笔记本测试，但如果机械结构没固定好，很其实很容易出现数据丢包。 3.目前是依赖Ubuntu 和ROS的。 4.5 .MCU、相机是可以替换的。这里，只是提供一个验证过的方案，方便大家复现FAST-LIVO。

感谢您的方案，请问是否考虑开源STM32模拟输出GPRMC信号用于时间同步的代码，否则还依赖于外部的GPS设备提供GPRMC报文

xuankuzcr, 2024-05-27:
是pps+gprmc。LiDAR内部会进行10分频，以10Hz的频率进行分帧。

Closed 2024-05-27.

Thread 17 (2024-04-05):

lens link broken

gc625-kodifly, 2024-04-05:
Hi, the taobao link for the lens is not working:
https://m.tb.cn/h.5l9xs3N?tk=R8R0W4cxQUF

xuankuzcr, 2024-05-27:
The link has been fixed.

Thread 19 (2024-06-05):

Cabling configuration using livox convertor and avia

gc625-kodifly, 2024-06-05:
in the readme you said that PIN 11 is connected to RS485_B and PIN 12 is connected to RS485_A. I am using the livox convertor with the sync cable, so I just want to confirm whether RS485_A corresponds to pin 2 on the sync cable and RS485_B corresponds to pin 1 on the sync cable
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

xuankuzcr, 2024-06-28:
You can refer to these cabling configuration pictures.
If you use the converter2.0, follow this:
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
If you connect LiDAR directly to the STM32, follow this:
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
In our setup, LiDAR is directly connected, but both options are possible. Using a converter is more convenient.

xuankuzcr, 2024-06-28:
If you are using a converter, you can directly connect the TTL level generated by the STM32 to the sync cable. The RS485 conversion mentioned in the readme is not needed.

eung-ark, 2024-11-08:
hello. I am a student studying. First of all, thank you for sharing such great code and content.
 I have a question.
When connecting using converter 2.0 as in the case above, is the Ethernet port not connected to anything? Or should I connect the converter and PC with an RJ45 cable?

thank you

xuankuzcr, 2024-11-12:
> hello. I am a student studying. First of all, thank you for sharing such great code and content. I have a question. When connecting using converter 2.0 as in the case above, is the Ethernet port not connected to anything? Or should I connect the converter and PC with an RJ45 cable?
>
> thank you

Yes, connect the converter to your computer with an RJ45 cable.

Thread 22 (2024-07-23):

camera timestamp is 0

gc625-kodifly, 2024-07-23:
after configuring the hardware for synchronization, I believe the sensors are now synchronized, however I noticed which I view recorded data using `rqt_bag`, I noticed that secs and nsecs is both 0.

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

furthermore, I noticed that the arrival time of the camera image seems to be slightly delayed, is this expected?
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

in `mvs_ros_pkg/src/grab_trigger.cpp` I've added some print statements:
```
      msg->header.stamp = rcv_time;
      printf("time_pc:%f\n", time_pc);
      printf("pointt->low:%d\n", pointt->low);
      pub.publish(msg);
```

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

it appears that the high and low attrributes of `pointt` is never set. I've checked that the timestamp file exists:
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

I'm currently launching them in separate terminals like
term 1: `roslaunch livox_ros_driver livox_lidar_rviz.launch `
term 2: ` roslaunch mvs_ros_pkg mvs_camera_trigger.launch`

xuankuzcr, 2024-07-25:
It is recommended to carefully read the bolded notes in this repository. Additionally, you should use `roslaunch livox_ros_driver livox_lidar_msg.launch`. You can re-pull the camera and LiDAR drivers under this repository and follow the instructions in the readme to execute the operations.

Closed 2024-08-02.

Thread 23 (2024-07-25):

undefined reference to "libusb set optton

85256638, 2024-07-25:
After install the Camera driver provided in mvs_ros_pkg. I couldn't successfully complie the FASTLIVO using CATKIN_make.

**Error:**
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

**Solution:**
Remove the libusb file in /opt/MVS/lib/64

Just wanted to post it here in case anyone faces the same issue.

xuankuzcr, 2024-08-01:
Thank you for your feedback and for sharing the solution!

Closed 2024-08-01.

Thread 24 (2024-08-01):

[mvs_camera_trigger-2] process has died

85256638, 2024-08-01:
After excuting the "roslaunch mvs_ros_pkg mvs_camera_trigger.launch". I receive the following error:

[mvs_camera_trigger-2] process has died [pid 17163, exit code -11, cmd /home/85256638/catkin_ws/devel/lib/mvs_ros_pkg/grabImgWithTrigger /home/85256638/catkin_ws/src/LIV_handhold-main/mvs_ros_pkg/config/left_camera_trigger.yaml __name:=mvs_camera_trigger __log:=/home/changning/.ros/log/3b057264-4fc6-11ef-bb51-9111640b0658/mvs_camera_trigger-2.log].

xuankuzcr, 2024-08-01:
Open the Hiki Robot SDK, find the serial number of your camera, and then enter it into the `SerialNumber` field in the `left_camera_trigger.yaml` config file.

85256638, 2024-08-01:
> Open the Hiki Robot SDK, find the serial number of your camera, and then enter it into the `SerialNumber` field in the `left_camera_trigger.yaml` config file.

Hi thanks a lot for your prompt reply.

I have already set the correct SN number in the `left_camera_trigger.yaml` file, but the same error persists.

I've also set the trigger mode on in the Hiki Robot SDK.

xuankuzcr, 2024-08-01:
Sorry, but it seems no one has encountered this problem before. Could you please identify which line of code is causing the error? Just because the sample code works correctly doesn't necessarily mean that the settings in this package are correct. Our driver settings are more extensive, and the functionality is more complex.

85256638, 2024-08-01:
> Sorry, but it seems no one has encountered this problem before. Could you please identify which line of code is causing the error? Just because the sample code works correctly doesn't necessarily mean that the settings in this package are correct. Our driver settings are more extensive, and the functionality is more complex.

Ok thanks anyway, I will dig it further and report here.

xuankuzcr, 2024-08-01:
By the way, please check if the wiring is correct, as the sample code uses the simplest video capture method without needing a trigger.

85256638, 2024-08-01:
> By the way, please check if the wiring is correct, as the sample code uses the simplest video capture method without needing a trigger.

Really appreciate your help!

I checked my wiring, indeed I mixed Camera's power ground `GND` with the Camera's Line 2 `OPTO_GND`, I should have connect the `OPTO_GND` with the Livox Converter'
s Ground cable, but the same error persists after I correct my wring.

Below is my detailed wiring diagram:

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

I can confirm the Lidar is synced:
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

xuankuzcr, 2024-08-02:
Could you please identify which line of code is causing the error?

85256638, 2024-08-02:
> Could you please identify which line of code is causing the error?

I almost pulled my hair out trying to get to the bottom of this issue. I added the following to the `mvs_camera_trigger.launch` launch file.

`<node pkg="mvs_ros_pkg" type="grabImgWithTrigger" name="mvs_camera_trigger" output="screen" args="$(find mvs_ros_pkg)/config/left_camera_trigger.yaml" launch-prefix="gdb --ex=run --args"/>`

The debug output is below:
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

85256638, 2024-08-02:
The author kindly helped me debug the issue.
The root cause of the problem was that I used the MV-CI013-A0UC camera, which does not support the RGB pixel format.

Thanks again for providing such a high quality project and and for your dedication to the community.

cchester25, 2025-04-03:
> The author kindly helped me debug the issue. The root cause of the problem was that I used the MV-CI013-A0UC camera, which does not support the RGB pixel format.
>
> Thanks again for providing such a high quality project and and for your dedication to the community.

您好，我也遇到了这样的问题，请问您的相机在客户端中能否选择为RGB格式呢？最后您使用的是什么格式的数据呢？非常期待您的解答，谢谢您！

luliang520, 2025-05-27:
你好,我这边在启动mvs_ros_driver的launch文件时也遇到了类似的错误,能方便交流一下嘛?我用的是 MV-CI013-A0UC相机,然后是安装了mvs之后,连接usb单独测试的,还没有做硬同步这个操作.
[device 0]:
Device Model Name: MV-CU013-A0UC
SerialNumber: DA5819648
[INFO] [1748338504.717589563]: Set ExposureAutoMode: Off
[INFO] [1748338504.723516562]: Set Exposure Time: 5000us
[INFO] [1748338504.726458268]: Set Gain Auto: Continues
[INFO] [1748338504.803670684]: Set GammaSlector: sRGB
[INFO] [1748338504.957870395]: Set Gamma: 0.700000
[INFO] [1748338504.960111524]: Finish all params set! Start grabbing...
[mvs_camera_trigger-2] process has died [pid 49442, exit code -11, cmd /home/nvidia/demo/mvs_ros_driver/devel/lib/mvs_ros_driver/grabImgWithTrigger /home/nvidia/demo/mvs_ros_driver/src/mvs_ros_driver/config/left_camera_trigger.yaml __name:=mvs_camera_trigger __log:=/home/nvidia/.ros/log/dd6ec46c-3add-11f0-838d-3c6d66186c78/mvs_camera_trigger-2.log].
log file: /home/nvidia/.ros/log/dd6ec46c-3add-11f0-838d-3c6d66186c78/mvs_camera_trigger-2*.log
[mvs_camera_trigger-2] restarting process
process[mvs_camera_trigger-2]: started with pid [49499]

Closed 2024-08-02.

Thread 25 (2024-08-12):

Is the lidar triggered like a camera?

SanghyunPark01, 2024-08-12:
The camera is a method of capturing an image when it is a rising edge by triggering at pps, when I look at the Livox time synchronization documentation, it seems to be a "time" (clock) synchronization operation, not a capture method through triggering. Does the lidar also have caputre data in the pps signal?

xuankuzcr, 2024-08-12:
Thank you for your attention. Livox LiDAR cannot capture data through a PPS signal trigger. The scan segmentation mechanism of Livox LiDAR is based on the integer seconds of ROS time. However, if you use PPS along with GPRMC (to create a simulated integer-second timestamp), it can effectively be considered as segmenting scans at the rising edge of the PPS signal.

SanghyunPark01, 2024-08-12:
Thank you for your answer. So in the case of the synchronization you mentioned here,
Does it mean that the camera image frame and lidar frame are **not** coming in at the same time, but "clock" is set to the GPRMCdata time?

xuankuzcr, 2024-08-13:
No, they can be considered as **being captured at the same moment**, with both the camera image frame and the LiDAR scan synchronized to the synthetic GPRMC time.

SanghyunPark01, 2024-08-13:
Thank you for your answer. I used flir machine vision camera and configured it similar to this repo (1Hz gPRMC, 30Hz pwm to cam). In rosbag record, one out of three times should be captured at the same time as LiDAR, but the time stamp of lidar and camera was not right.
(The camera captures the image at the rising edge.)

could you give me some advice on how to solve it?

xuankuzcr, 2024-08-13:
Please note that our camera driver has been modified. We store the timestamp from the LiDAR scan header into the shared memory and assign it to the corresponding camera frame. Your FLIR camera driver will also need to perform this operation. For every three image frames, copy the LiDAR scan timestamp to the camera frame. For the other two image frames, add 33.33ms and 66.66ms to the timestamp of the first frame, respectively.

SanghyunPark01, 2024-08-13:
Thank you so much for the advice! :smiley:

xuankuzcr, 2024-08-14:
You're welcome! If there are no further concerns, you can go ahead and close this issue.

Closed 2024-08-14.

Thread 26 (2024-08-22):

雷达与相机的时间戳相同是必须的吗？

JinMing-Gu, 2024-08-22:
作者你好！

我看了一些时间延迟补偿的论文，我理解之所以需要时间延迟补偿，是因为多传感器系统中，每个传感器数据时间戳与其真实采样时刻之间存在时延(或者说时间戳无法反映传感器的真实采样时刻)，那么：
1. 如果传感器数据时间戳与其真实采样时刻相同，但是多个传感器的时间戳不相等，这种情况下是否需要时间延迟补偿，还是说仅依靠时间差做插值即可；

2. 我下载了FAST-LIVO中的数据集，发现LiDAR与Camera的时间戳完全一致，使得多个传感器的时间戳相等，这是必须要做的吗？还是说只要保证传感器数据时间戳与其真实采样时刻相同，就是没有时间延迟的系统了？

总之，我理解时钟源一致，时间戳与传感器真实采样时刻一致是必要的。那么在此前提下，是否一定要求多传感器的时间戳也要相同？

希望作者可以解答疑问，感谢！

xuankuzcr, 2024-08-27:
感谢你的关注！
1. 如果传感器数据时间戳与其真实采样时刻相同，则不需要时间延迟补偿。[FAST-LIVO](https://arxiv.org/pdf/2203.00893)会进行异步更新，在LiDAR和image的各自采样时刻更新，[FAST-LIVO2](https://arxiv.org/pdf/2408.14035)会先将LiDAR原始点云在相机时间戳处分帧来保证和图像对齐，然后再做同步更新(sequential update)。
2. 可以不相等，只要在同一个时间轴上，也就是你提到的“传感器数据时间戳与其真实采样时刻相同”，就认为是没有延迟的数据。

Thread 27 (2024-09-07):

您好 打扰您了，我采用硬件设备为MID360+STM32做硬件同步，且使用串口助手检测PA9串口可以发出以下文本

wangdebin00223, 2024-09-07:
$GPRMC,000601.00,A,2237.496474,N,11356.089515,E,0.0,225.5,080924,2.3,W,A2E
$GPRMC,000602.00,A,2237.496474,N,11356.089515,E,0.0,225.5,080924,2.3,W,A2D
$GPRMC,000603.00,A,2237.496474,N,11356.089515,E,0.0,225.5,080924,2.3,W,A2C
$GPRMC,000604.00,A,2237.496474,N,11356.089515,E,0.0,225.5,080924,2.3,W,A2B
$GPRMC,000605.00,A,2237.496474,N,11356.089515,E,0.0,225.5,080924,2.3,W,A2A
$GPRMC,000606.00,A,2237.496474,N,11356.089515,E,0.0,225.5,080924,2.3,W,A29
$GPRMC,000607.00,A,2237.496474,N,11356.089515,E,0.0,225.5,080924,2.3,W,A28
$GPRMC,000608.00,A,2237.496474,N,11356.089515,E,0.0,225.5,080924,2.3,W,A27
$GPRMC,000609.00,A,2237.496474,N,11356.089515,E,0.0,225.5,080924,2.3,W,A*26
但是我将STM32的PA9和PB5分别接入MID360线的10号和8号线，在LivoxViewer查看Time Sync Type :显示 No Sync
并且有警告。能麻烦您帮忙分析一下，是哪里的问题吗？卡在这里好久了，一直排查不出来十分感谢!!!!
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

yunliuh, 2024-09-11:
接上地线试试

xuankuzcr, 2024-09-20:
可以在fast-livo仓库继续讨论，这里我有时候看不到，我只watch了livo的仓库。后续有问题在那里同步。

Closed 2024-11-10.

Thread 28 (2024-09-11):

Is there a fixed deviation between the LiDAR frame and camera frame?

yunliuh, 2024-09-11:
Hello, upon reviewing your code, I’ve noticed that the time synchronization between the LiDAR and the camera is achieved by sharing the timestamp from the LiDAR scan header. This aligns the camera frame timestamps with each LiDAR scan timestamp. However, theoretically, the trigger moments for the LiDAR and the camera are not the same. Therefore, should there be a fixed deviation between them (since the camera is triggered by a 10Hz PWM signal, whereas the LiDAR is not triggered by a PPS signal)?

xuankuzcr, 2024-09-20:
There is no fixed delay; the time deviation mainly consists of the variable exposure time and ISP processing time.
Let me explain the basic principle. All sensors are hard-synchronized using a 10 Hz trigger signal generated by synchronized timers on the STM32. Note that the Livox converter only supports a 1 Hz Pulse Per Second (PPS) trigger signal, and the Livox SDK automatically subdivides this into 10 Hz. Additionally, to segment the Livox LiDAR point cloud into scans at the rising edge of the square wave, we use the STM32 to generate a synthetic (false) GPRMC (containing an integer-second timestamp) and transmit it to the onboard PC via serial communication at 1 Hz. The Livox SDK then assigns the decoded timestamp to the LiDAR scan header, and the same timestamp is also applied to the corresponding camera image frame header, as the camera is triggered by the same rising edge. Since solid-state LiDAR lacks a scan synchronization signal, this approach ensures reliable hard synchronization, especially in indoor environments where GPS signals are unavailable.

mkarklins, 2025-03-08:
Wanted to clarify.

In the livox_ros_driver2 I couldn't find code which would read the serial containing the fake GPRMC messages. This seems to be present only in livox_ros_driver (old).

Is it correct to assume that when using MID360 with livox_ros_driver2 the GPRMC messages should be sent from the STM32 directly to the MID360 via serial ( data/function cable ), so that the packets from the MID360 already contain the precise timestamps in the header, hence can be stored in /timeshare?

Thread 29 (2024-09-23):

ARM compiler issue

HXB-1997, 2024-09-23:
Rebuild started: Project: PWM
*** Error: The configured compiler version '5.06 update 7 (build 960)' does not support the selected User Based Licensing technology.
*** Rebuild aborted.
Build Time Elapsed:  00:00:00

xuankuzcr, 2024-10-03:
The bug has been fixed, you can pull the changes and rebuild.

HXB-1997, 2024-10-04:
> The bug has been fixed, you can pull the changes and rebuild.

thanks a lot. I fixed by my own, after I deactivate keil and reactivate.

Closed 2024-10-04.

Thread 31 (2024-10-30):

The battery's link is not connected.

eung-ark, 2024-10-30:
If you don't mind, could you please update the battery purchase link?
Thank you.

eung-ark, 2024-11-04:
I have a question. Do I have to use a 24v battery? Is it not possible to use a 12v battery?

always Thank you.

Es1erda, 2024-11-04:
That depends on the power requirements of the devices you're using. Using a 12V battery is certainly feasible, but you may need to prepare some step-up and step-down voltage modules to meet the necessary power specifications.

Closed 2024-10-31.

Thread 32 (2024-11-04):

imu loop back

yangqifan913, 2024-11-04:
频繁地报错imu loop back，clear buffer。看IMU数据经常会回滚到过去一段时间，然后又恢复正常。不进行时间同步就不会出现这个问题。
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

yangqifan913, 2024-11-04:
忘了说用的是mid360

xuankuzcr, 2024-11-04:
1. 检查下是否供地，以及买的网线是否有屏蔽层。2. 如果实在无法修复的话，可以在imu的回调函数里面加一句，如果上一个imu msg的时间戳小于当前帧imu的话，就把回退的时间补偿回来。3. 也可以直接在livox_ros_driver里面修复，用下面代码替换这个函数。**[但正常接线没问题的话应该是没有回退的]**
```cpp
uint32_t Lddc::PublishImuData(LidarDataQueue *queue, uint32_t packet_num,
                              uint8_t handle) {
  volatile uint64_t timestamp = 0;
  uint32_t published_packet = 0;

  sensor_msgs::Imu imu_data;
  imu_data.header.frame_id = "livox_frame";

  uint8_t data_source = lds_->lidars_[handle].data_src;
  StoragePacket storage_packet;
  QueuePrePop(queue, &storage_packet);
  LivoxEthPacket *raw_packet =
      reinterpret_cast<LivoxEthPacket *>(storage_packet.raw_data);
  timestamp = GetStoragePacketTimestamp(&storage_packet, data_source);
  if (timestamp >= 0) {

    if (timestamp_last_imu_ > timestamp) {
      diff_t_imu_ = timestamp_last_imu_ - timestamp;
    }

    if (diff_t_imu_ > 39809238968) {
      cnt_imu_ = ((int)((float)diff_t_imu_ / 40000000000.0));
      timestamp = timestamp + (cnt_imu_ + 1) * 40000000000;
    }
    imu_data.header.stamp =
        ros::Time(timestamp / 1000000000.0); // to ros time stamp
    timestamp_last_imu_ = timestamp;
  }

  uint8_t point_buf[2048];
  LivoxImuDataProcess(point_buf, raw_packet);

  LivoxImuPoint *imu = (LivoxImuPoint *)point_buf;
  imu_data.angular_velocity.x = imu->gyro_x;
  imu_data.angular_velocity.y = imu->gyro_y;
  imu_data.angular_velocity.z = imu->gyro_z;
  imu_data.linear_acceleration.x = imu->acc_x;
  imu_data.linear_acceleration.y = imu->acc_y;
  imu_data.linear_acceleration.z = imu->acc_z;

  QueuePopUpdate(queue);
  ++published_packet;

  ros::Publisher *p_publisher = Lddc::GetCurrentImuPublisher(handle);
  if (kOutputToRos == output_type_) {
    p_publisher->publish(imu_data);
  } else {
    if (bag_ && enable_imu_bag_) {
      bag_->write(p_publisher->getTopic(), ros::Time(timestamp / 1000000000.0),
                  imu_data);
    }
  }
  return published_packet;
}
```

xuankuzcr, 2024-11-04:
别忘了定义这几个成员变量在class Lddc里。
```cpp
volatile uint64_t timestamp_last_imu_ = 0;
volatile uint64_t diff_t_imu_;
volatile int cnt_imu_;
```

85256638, 2024-11-10:
我也出现了同样的错误

> 频繁地报错imu loop back，clear buffer。看IMU数据经常会回滚到过去一段时间，然后又恢复正常。不进行时间同步就不会出现这个问题。 ![Screenshot from 2024-11-04 15-52-26](https://private-user-images.githubusercontent.com/59222516/382677930-07df90f5-7167-432c-8b4d-11ee286075f4.png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)

我也出现同样的错误了，把雷达同步线拔了就没出现错误了。。请问你这个IMU数据界面怎么展示的？

Torchmm, 2024-11-25:
@xuankuzcr 你好，共地是需要电源地和功能线的地线共地吗？

85256638, 2024-11-28:
> @xuankuzcr 你好，共地是需要电源地和功能线的地线共地吗？

@Torchmm ,我之前被这个问题困扰了很久了，一直是IMU loop back。。。 现在终于搞明白了。

**我之前的情况是这样的：**
整个系统里面有两块电池。第一块是笔记本自带的电池， SMT32通过USB-TTL接笔记本的USB口。 激光雷达是有另外一个12V充电宝。

**现在改成：**
整个系统里面有两块电池。第一块是笔记本自带的电池， SMT32通过USB-TTL接笔记本的USB口。 激光雷达是有另外一个12V充电宝。 把12V充电宝的负极用导线连接到SMT32的地线。。。。 问题解决。。。

@xuankuzcr 郑博，可能不少新手和我一样犯这个错误导致他们没有复现成功。可以把这个放到首页里面说明一下，避免他们踩同样的坑。

xuankuzcr, 2024-12-01:
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

感谢~我有空把**共地**放到readme里面强调下

Torchmm, 2024-12-02:
@xuankuzcr @85256638 我是一个电池，并且stm32板子和数据采集主板已经共地了，而且信号线的地也共上了，就是说，STM32的地，嵌入式主板的负极，和信号线的地线共在一起了。数据频繁回退。

Torchmm, 2024-12-02:
@85256638 @xuankuzcr 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
我把一段时间的数据时间戳绘制出来，发现近似规律性的回退。

85256638, 2024-12-03:
> @xuankuzcr @85256638 我是一个电池，并且stm32板子和数据采集主板已经共地了，而且信号线的地也共上了，就是说，STM32的地，嵌入式主板的负极，和信号线的地线共在一起了。数据频繁回退。

你这里的"信号线"指的是激光雷达的那个M12线？ 给激光雷达供电的那个线也得和STM32供一个地。 另外你不要用livox 官方的ROS driver。 你要用作者提供的 ROS driver，他做过修改：

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

Torchmm, 2024-12-03:
@85256638 对，信号线指的是1HZ的PPS信号，他的地线也和电源共线了。

85256638, 2024-12-04:
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

你参考一下我的连接方式，另外你用了作者的Livox ROS 驱动

Torchmm, 2024-12-04:
@85256638 好的，谢谢您，我找到问题了，是模拟的GPS的时间没有按照分秒的60进制和小时的24进制发送的问题。

xuankuzcr, 2024-12-04:
**注：使用新版STM32固件，该Bug之前就修复了 (如下图红框所示)。**
旧版固件中，每隔100秒会回退40秒，这是因为在99到100秒进位时，时间会跳变为1分钟，导致回退40秒的问题。因此，需要按照`分秒的60进制和小时的24进制`格式发送GPRMC数据。
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

Torchmm, 2024-12-04:
@xuankuzcr 好的，十分感谢，已经修复。

RayRua, 2025-05-21:
请问一下硬同步后时间戳对齐是如何实现的

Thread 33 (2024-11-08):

Alternative Camera and Recommended Onboard Computer Model

nyagato-00, 2024-11-08:
Hello,

Firstly, I would like to express my sincere gratitude for the resources shared in this repository. The information and tools provided have been incredibly valuable, and I truly appreciate the work and detail that has gone into this project.

I’m currently working to replicate this setup and am facing challenges in sourcing the MV-CA013-21UC camera within Japan. Therefore, I would like to inquire if an alternative camera could be used without issues.

1.	Alternative Camera Options
We are considering the FLIR BFS-U3-16S2C-CS as a replacement for the MV-CA013-21UC. This camera meets similar requirements, including resolution, frame rate, USB 3.0 interface, and Linux compatibility. Could this camera work seamlessly with the system? Additionally, if there are any recommended alternatives that would be better suited, we would appreciate any suggestions.

2.	Onboard Computer Recommendations
For the onboard computer, we are evaluating the NVIDIA Jetson Nano and Raspberry Pi 4 Model B. Would these models be appropriate for handling the real-time processing of LiDAR and camera data in this project? Alternatively, if there is a more suitable model for our needs, could you please advise on this? We are particularly interested in the required performance specifications and interface compatibility with both the camera and LiDAR.

Thank you very much again for your guidance and for the invaluable resources provided in this repository.

SanghyunPark01, 2024-11-08:
To tell you my experience

1. Alternative Camera Options
I composed the camera you want to use and it worked well. However, you need to modify the spinnaker ros driver.
By implementing file IO using memory mapping(mmap in C++), Timestamp can be shared with other sensors.

2. Onboard Computer Recommendations
Are you talking about FAST-LIVO? It's going to work without problems with data acquisition.
If there is a problem with computing performance, I recommend to acquire the data(rosbag) and run it on another computer.

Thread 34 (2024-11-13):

Images are way too dark on MVS viewer.

eung-ark, 2024-11-13:
Is the model of the camera lens on the handhold [MVL-HF0628M-6MPE] correct?

When I check it in Ubuntu MVS camera viewer, the image itself comes out too dark.

The aperture has also been opened to the maximum.

Does it change when I install the camera driver and trigger it?

should I up the gain?

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

Thank you.

Closed 2024-11-16.

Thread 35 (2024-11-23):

mvs的驱动可以更改图像的分辨率吗

JACKLiuDay, 2024-11-23:
郑博好，我想问下，我打算修改mvs驱动，把相机的分辨率从600提高到1280，需要找哪个地方啊，yaml配置文件里并没有分辨率参数啊

mumu2822, 2025-03-24:
> 郑博好，我想问下，我打算修改mvs驱动，把相机的分辨率从600提高到1280，需要找哪个地方啊，yaml配置文件里并没有分辨率参数啊

你好，请问这个问题你解决了吗，我A0UC的分辨率弄出来也只有640×512

mumu2822, 2025-03-24:
> > 郑博好，我想问下，我打算修改mvs驱动，把相机的分辨率从600提高到1280，需要找哪个地方啊，yaml配置文件里并没有分辨率参数啊
>
> 你好，请问这个问题你解决了吗，我A0UC的分辨率弄出来也只有640×512

没事了，image_scale改一下就好了，默认是0.5，刚才没有看见😂

Closed 2024-11-23.

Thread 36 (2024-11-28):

time sync error

eung-ark, 2024-11-28:
I am working on configuring the Livox converter. Should the ground wire from the converter and the ground wire from the camera both be connected to a single ground terminal on the STM32 board? The timestamp synchronization between the LiDAR and the camera is not working consistently. The STM32 board has multiple ground terminals; is it possible to connect each wire to a separate ground terminal instead?

The ROS signals from both the LiDAR and the camera seem to be coming in at 10 Hz. However, the synchronization is consistently off by around 0.03 seconds.

Thank you always.

xuankuzcr, 2025-01-20:
1. As long as they share a common ground, there's no need to connect everything to a single terminal.
2. The ROS delay between LiDAR and the camera is not a true time difference; as long as the LiDAR and image measurements (i.e., timestamps) are aligned, there should be no issue running FAST-LIVO.

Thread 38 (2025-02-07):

Inquiry About FOV Calculation and Camera Selection

HyoyeonLee, 2025-02-07:
Hello,

I appreciate the work put into LIV_handhold, FAST-LIVO, and FAST-LIVO2, as well as the effort in making the code and datasets available.

I am currently in the process of selecting sensors and other components to set up the hardware for reproducing your work and have two questions.

**[Q1] FOV Calculation**

   According to the FAST-LIVO2 paper and [FAST-LIVO2-issue#34](https://github.com/hku-mars/FAST-LIVO2/issues/34), the Private Dataset uses the [MVL-HF0628M-6MPE](https://www.innosmart.bg/wp-content/uploads/CSM/HIKROBOT/product_docs/MVL-HF0628M-6MPE_datasheet_20221022--innosmart.bg--.pdf) (or [LM5JCM](https://pyramidimaging.com/specs/Kowa/LM5JCM.pdf)) lens with the [MV-CA013-21UC](https://www.rmaelectronics.com/content/HikRobot/CameraDatasheets/USB3.0AreaScan/MV-CA013-21UMUCDat%20Sheet.PDF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) (1/2” sensor) camera, achieving a FOV of 70.6°(H) x 68.5°(V).
   However, based on the lens specifications of MVL-HF0628M-6MPE, the expected FOV for a 1/1.8” sensor is 63.11°(H) x 44.59°(V).
   Given that a 1/2” sensor is smaller, I would expect it to result in an even narrower FOV of 54.8°(H) x 42.5°(V).
   In the case of the LM5JCM lens, a FOV of 65.2°(H) × 51.3°(V) is specified for a 1/2" sensor.
   I would appreciate if you could share how the FOV (70.6° × 68.5°) was determined.

**[Q2] Camera Replacement**

   Since the [MV-CA013-21UC](https://www.maxxvision.com/downloads/Cameras/USB30/Hikrobot/Hikrobot_MV-CU013-A0UMUC.pdf) has been discontinued, I am considering using  the MV-CU013-A0UC camera. As mentioned in [LIV_handhold-issue#24](https://github.com/xuankuzcr/LIV_handhold/issues/24), with the addition of BayerGB support to `mvs-ros-pkg`, would this camera be fully compatible?

   I appreciate your time and look forward to your insights.

Best regards,

xuankuzcr, 2025-02-16:
A1: The lens in the paper is custom-made, so it's not possible to find an exact match. The LM5JCM has a FoV of (Hor. x Ver. x Dia.) 82.4° x 66.9° x 95.0° on a 2/3" sensor. You could consider switching to a 2/3" CMOS sensor, such as the MV-CS050-10UC.

A2: Don't worry, it's fully compatible. If there are any issues, feel free to raise an issue, and I will respond promptly.

HyoyeonLee, 2025-02-17:
> A1: The lens in the paper is custom-made, so it's not possible to find an exact match. The LM5JCM has a FoV of (Hor. x Ver. x Dia.) 82.4° x 66.9° x 95.0° on a 2/3" sensor. You could consider switching to a 2/3" CMOS sensor, such as the MV-CS050-10UC.
>
> A2: Don't worry, it's fully compatible. If there are any issues, feel free to raise an issue, and I will respond promptly.

Thank you so much for your help and confirmation! I was looking for a camera with an FOV similar to or slightly larger than my LiDAR's, so I’ve decided to go with the camera and lens you recommended. I really appreciate you sharing the model names, as it makes integrating them with your repo much easier.

xuankuzcr, 2025-02-17:
You're welcome! Glad I could help, and I hope the setup works perfectly for your project. If you ever need further assistance, don't hesitate to reach out. It's always great to see the community putting our work to good use—looking forward to seeing what you create! 😊

Closed 2025-02-17.

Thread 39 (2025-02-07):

是否只使用STM32不使用RS485和TTL2USB

yubo105139, 2025-02-07:
我在复现时候看着接线表中有RS485和TTL2USB，我是否可以直接将PA1连接到MVS camera PIN2，GND连接MVS camera PIN5 (GND)。是STM32的PB5连接LiDAR M12 PIN12 (Sync+)，PA9连接LiDAR M12 PIN11 (Sync-)，GND连接LiDAR M12 PIN2 (GND)。而不使用RS485和TTL2USB作为中间件进行连接？

xuankuzcr, 2025-02-16:
不接Livox convertor的时候一定要转485电平

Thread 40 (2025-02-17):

MID360 PPS秒脉冲触发

leoxiang66, 2025-02-17:
我向Mid 360的技术确认过了， MID360不支持秒脉冲触发，
请问这里是如何实现lidar和相机PPS秒脉冲同步触发的呢

xuankuzcr, 2025-02-17:
Mid360不支持外部触发pps，但支持pps+GPRMC模式。更多细节见 #28。

leoxiang66, 2025-02-17:
> Mid360不支持外部触发pps，但支持pps+GPRMC模式。更多细节见 [#28](https://github.com/xuankuzcr/LIV_handhold/issues/28)。

好的 谢谢

Closed 2025-02-17.

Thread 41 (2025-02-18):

运行roslaunch mvs_ros_pkg mvs_camera_trigger.launch出现错误

mikedh-avia, 2025-02-18:
运行相机launch文件以后拍照出现process has died 错误，报错和issue 24提到的一样。在客户端中pwm可以成功采集图像，频率也为10HZ但是运行launch文件出错，序列号已经调整为正确的了，修改了PixelFormat为0，1，2，3均报错。接线应该没有问题，PA1接上pin2，地接上pin5。麻烦帮我看一看问题在哪里

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

mikedh-avia, 2025-02-18:
这是具体的报错信息：

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

mikedh-avia, 2025-02-18:
作者很热心的帮我解决了！是opencv的版本出现问题！再次感谢帮助

Closed 2025-02-18.

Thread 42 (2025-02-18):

相机的参数设定

yeyiru, 2025-02-18:
郑博您好，
我和这个文档里面采用了类似参数的镜头（F-2.8）和相机（1/2"）组合，使用left_camera_trigger.yaml 这个文件的参数后发现，和FAST-LIVO2的dataset中画面的亮度相比画面比较暗，
所以想问下您在收集FAST-LIVO2的dataset中的相机参数和left_camera_trigger.yaml 这个文件里设置的一样吗？
或是还有使用什么后端的图像增强手段吗？
谢谢

yeyiru, 2025-02-19:
> 参数不一样，要自己调一下，主要是设置小范围自动曝光+自动增益

感謝！

Closed 2025-03-05.

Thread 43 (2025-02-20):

Is it possible to use a raspberry pi camera module v2?

GeomPozzoli, 2025-02-20:
Good morning,
congratulations for this open-source project
I wanted to try using a raspberry pi 4 and a livox mid-360 for data acquisition (data to be used later on another PC), but it is not clear to me if it is possible to use a pi camera module v2 as a camera, also considering the fact that it only has the ribbon cable and it is not possible to connect the opto-in and ground as in the project to the stm32.
Is it possible to manage data synchronization in another way, or do you have any suggestions for entry-level camera models compatible with the project's connections to do some experiments with?
Sorry if the question is a bit stupid but I don't have much knowledge about mvs cameras
Greetings
Stefano

xuankuzcr, 2025-02-21:
Hi Stefano,

Thanks for your question! For the Pi Camera Module V2, please check its manual to confirm if it supports external sync triggering. If not, you might need a camera that supports hardware triggering, such as FLIR Blackfly S, Basler ace series.

GeomPozzoli, 2025-03-05:
thanks for the reply,
I verified that the pi camera module v2 does not support external trigger hardware
I found a model of the inno maker CAM-IMX296Color-GS, which supports the trigger but the output format is YUV and not RGB, and I can't understand if it is compatible with the mvs_ros, do you have any info about it because in the code I see that there is only

> PixelFormat: 0 # 0: RGB8, 1: BayerRG8, 2: BayerRG12Packed, 3: BayerGB12Packed

Regards
Stefano

GeomPozzoli, 2025-03-06:
I probably need to use the camera type/brand related driver and not the mvs_ros_pkg.......................

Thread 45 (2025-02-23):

Also imu and lidar time loop back

zhSlamer, 2025-02-23:
作者以及同学们你们好！我是遇到了激光雷达时间戳和IMU时间戳同时回退的问题
激光雷达为设备：Horizon
我认真审阅了issue32-imu loop  back的内容 #32，
一是供地：我将激光雷达的供电源的地与STM32地连接
二是我烧录的是最新的STM32源码，查看打印的GPRMC的时间符合hhmmss格式，符合满60进位,并且具有校验位
但仍然出现了时间戳周期性的回退，大致是4s内就会有变化，具体现象如下图：
向大家请求帮助，感谢作者和同学们！

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

zhSlamer, 2025-02-24:
观察数据，回退的时间为1s，即时间戳为68.9时，下一帧应为69.0，而此时又回到了68.0，即重复了时间戳，导致时间回退，并且经过几秒后，跳跃一秒，如从此时68.0开始68.0，68.1，...,**68.9，68.0，68.1**，68.2，...，72.8，**72.9，74.0，**74.1

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

zhSlamer, 2025-02-24:
问题解决了，因为TTL2USB丢包了，数据总是发布完整，还好我们有个新的TTL2USB，换了之后立马好了

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

wwtx, 2025-05-07:
@zhSlamer 请问如何查看TTL2USB是否丢包了？

zhSlamer, 2025-05-08:
> [@zhSlamer](https://github.com/zhSlamer) 请问如何查看TTL2USB是否丢包了？

你使用cutecom看看数据每一次打印的是否是完整的一整条数据，如果还不行，就改波特率

Closed 2025-02-25.

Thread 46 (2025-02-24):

docker下timeshare的读写问题

LauZanMo, 2025-02-24:
你好，感谢你的开源！

我现在正在尝试将这个工程集成进docker中，遇到了以下问题：

因为docker中默认使用的root权限，我将path_for_time_stamp的构建从：

```c++
  const char *user_name = getlogin(); // root权限下为nullptr
  std::string path_for_time_stamp = "/home/" + std::string(user_name) + "/timeshare";
```

改为了

```c++
  std::string path_for_time_stamp = "/root/timeshare";
```

但是启动时会出现文件存在，mvs_ros_pkg读取时却为pointt为MAP_FAILED的问题，想问问您的看法。

如果需要，我可以提供docker镜像，再次感谢！

xuankuzcr, 2025-02-25:
你好，LiDAR的driver里面的路径也要改

LauZanMo, 2025-02-26:
上述问题的背景是我对mvs_ros_pkg和livox_ros_driver2的路径都做了修改，为了让我的问题更清晰，我已将docker镜像打包上传至dockerhub，执行：

```bash
docker pull lauzanmo/driver:latest
```

即可拉取镜像，执行：

```bash
docker run -it --rm --gpus all --net=host \
	-e NVIDIA_DRIVER_CAPABILITIES=all \
	-e DISPLAY=$DISPLAY \
	-v $HOME/.Xauthority:/root/.Xauthority \
	-e LD_PRELOAD=/opt/MVS/lib/64/libMvCameraControl.so \
	-e MVCAM_COMMON_RUNENV=/opt/MVS/lib \
	--device /dev/bus/usb/ \
	-v /dev/bus/usb/:/dev/bus/usb/ \
	-v /opt/MVS/:/opt/MVS/ \
	driver:latest \
	bash -it -c "roslaunch livox_ros_driver2 handhold.launch"
```

即可在容器中运行，handhold.launch即为同时启动livox_ros_driver2 rviz_MID360.launch和mvs_ros_pkg mvs_camera_trigger.launch。

构建镜像的dockerfile如下：

```dockerfile
ARG BASE_IMAGE=ros:noetic
ARG ROS_WS=/root/catkin_ws
FROM ${BASE_IMAGE}

RUN apt-get update && \
    apt-get install -y --no-install-recommends \
    git wget nano libomp-dev build-essential python3-pip libopencv-dev \
    ros-${ROS_DISTRO}-eigen-conversions ros-${ROS_DISTRO}-cv-bridge \
    ros-${ROS_DISTRO}-image-transport-plugins \
    ros-${ROS_DISTRO}-pcl-ros ros-${ROS_DISTRO}-rviz && \
    apt-get clean && rm -rf /var/lib/apt/lists/*

WORKDIR /root
RUN git clone https://github.com/Livox-SDK/Livox-SDK2.git && \
    mkdir -p Livox-SDK2/build && \
    cd Livox-SDK2/build && \
    cmake .. && \
    make -j$(nproc) && \
    make install && \
    rm -rf /root/Livox-SDK2

COPY ./MVS/ /opt/MVS/

ARG ROS_WS
ENV ROS_WS=${ROS_WS}
COPY LIV_handhold/livox_ros_driver2 ${ROS_WS}/src/livox_ros_driver2
COPY LIV_handhold/mvs_ros_pkg ${ROS_WS}/src/mvs_ros_pkg
ENV LD_PRELOAD=/opt/MVS/lib/64/libMvCameraControl.so
WORKDIR ${ROS_WS}/src
RUN cd livox_ros_driver2 && \
    /bin/bash -c '. /opt/ros/${ROS_DISTRO}/setup.bash; ./build.sh ROS1' && \
    rm -r ${ROS_WS}/build/ && \
    sed --in-place --expression '$isource \"${ROS_WS}/devel/setup.bash\"' /ros_entrypoint.sh

WORKDIR /root
ENTRYPOINT ["/ros_entrypoint.sh"]
CMD ["bash"]
```

希望能得到你的帮助！

LauZanMo, 2025-02-27:
刚刚做了@pcl5 建议的尝试，都修改为“/tmp/timeshare”，依然是文件被创建，但是无法读取。

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

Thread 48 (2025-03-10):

STM32 PPS Signal Verification and Debugging

MattiasTancred, 2025-03-10:
Hello,

I'm quite new to STM32 development, and currently I'm attempting to set up the STM32 for this repo.

What I've done:

Hardware: STM32F103C8T6 (as recommended in the repository).
Firmware: Downloaded, compiled, and flashed the STM32 firmware from the repo using KEIL, STM32CubeIDE, and STM32CubeProgrammer. All built and flashed ok.
Wiring: Carefully connected everything according to the provided schematics (triple-checked to confirm accuracy). No converter.
ROS & Livox Viewer: ROS nodes run smoothly without errors. All ROS topics publish correctly.

The Issue:

When setting the parameter TriggerEnable: 0, I successfully receive LiDAR data and visualize it in RViz.
When changing the parameter to TriggerEnable: 1 (which I assume relies on the PPS synchronization from the STM32), the Livox Viewer shows no PPS signal, and RViz receives no data.

I suspect that the STM32 board isn't outputting the PPS signal correctly (or at all).

My Questions:

Visual Indicator:
Is the STM32 firmware designed to provide any visual indicator (such as blinking or constant illumination of the onboard PC13 LED) when it outputs a PPS signal on pin PB5?

Verification & Debugging (without oscilloscope):
Without access to an oscilloscope, what would you recommend as the best debugging steps to confirm:
The STM32 firmware was built and flashed correctly.
The STM32 firmware is actively running.
The PPS signal is actually being generated on PB5.

Any practical tips or common pitfalls regarding STM32 and Livox PPS synchronization would also be greatly appreciated!

Thank you very much in advance for your help - I really do not know were to start debugging :)

MattiasTancred, 2025-03-17:
Any suggestions @xuankuzcr ?
I have tried converter 2.0 and also the specified hardware setup in the repo without the converter.

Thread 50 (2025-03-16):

launch运行错误

dawalishi122, 2025-03-16:
roslaunch hikrobot_camera hikrobot_camera.launch
... logging to /home/nuc/.ros/log/044602c6-0262-11f0-94fa-fbcea1d3ebae/roslaunch-nuc-NUC13VYKi5-235393.log
Checking log directory for disk usage. This may take a while.
Press Ctrl-C to interrupt
Done checking log file disk usage. Usage is <1GB.

started roslaunch server http://nuc-NUC13VYKi5:45095/

SUMMARY
========

PARAMETERS
 * /ExposureTime: 70000
 * /FrameRate: 10
 * /FrameRateEnable: True
 * /GainAuto: 2
 * /Gamma: 0.7
 * /GammaEnable: True
 * /Offset_x: 0
 * /Offset_y: 0
 * /Saturation: 128
 * /SaturationEnable: False
 * /TriggerMode: 1
 * /TriggerSource: 0
 * /height: 320
 * /rosdistro: noetic
 * /rosversion: 1.17.0
 * /width: 640

NODES
  /
    hikrobot_camera (hikrobot_camera/hikrobot_camera)

ROS_MASTER_URI=http://localhost:11311

process[hikrobot_camera-1]: started with pid [235422]
[device 0]:
UserDefinedName:

set AcquisitionFrameRateEnable OK! value=1.000000
set AcquisitionFrameRate OK! value=10.000000
set Height OK!
set Width OK!
set Offset X OK!
set Offset Y OK!
set ExposureTime OK! value=70000.000000
set GammaEnable OK! value=1.000000
set Gamma OK! value=0.700000
set GainAuto OK! value=2.000000
set BalanceRatio OK! value=0.000000
set TriggerMode OK!
set PixelFormat OK ! value = RGB
PixelFormat :17301514!
[ INFO] [1742131044.363636623]: The Number of Faild Reading Exceed The Set Value!

[hikrobot_camera-1] process has died [pid 235422, exit code 255, cmd /home/nuc/catkin_ws/devel/lib/hikrobot_camera/hikrobot_camera __name:=hikrobot_camera __log:=/home/nuc/.ros/log/044602c6-0262-11f0-94fa-fbcea1d3ebae/hikrobot_camera-1.log].
log file: /home/nuc/.ros/log/044602c6-0262-11f0-94fa-fbcea1d3ebae/hikrobot_camera-1*.log

参考了其他的教程，测试修改line为其他的（0,1,2）均不可行，修改timeshare权限也不行。

Lianghongnan, 2025-03-23:
请问下你的相机型号是什么呢？

dawalishi122, 2025-03-23:
我解决了，就是港科大开源资料中提到的海康彩色相机。

ฅ՞•ﻌ•՞ต

---原始邮件---
发件人: ***@***.***&gt;
发送时间: 2025年3月23日(周日) 下午4:00
收件人: ***@***.***&gt;;
抄送: ***@***.******@***.***&gt;;
主题: Re: [xuankuzcr/LIV_handhold] launch运行错误 (Issue #50)

请问下你的相机型号是什么呢？

—
Reply to this email directly, view it on GitHub, or unsubscribe.
You are receiving this because you authored the thread.Message ID: ***@***.***&gt;
  Lianghongnan left a comment (xuankuzcr/LIV_handhold#50)

请问下你的相机型号是什么呢？

—
Reply to this email directly, view it on GitHub, or unsubscribe.
You are receiving this because you authored the thread.Message ID: ***@***.***&gt;

Lianghongnan, 2025-03-23:
额，是港大[@xuankuzcr](https://github.com/xuankuzcr)开源的

dawalishi122, 2025-03-23:
感谢纠正!

ฅ՞•ﻌ•՞ต

---原始邮件---
发件人: ***@***.***&gt;
发送时间: 2025年3月23日(周日) 下午4:07
收件人: ***@***.***&gt;;
抄送: ***@***.******@***.***&gt;;
主题: Re: [xuankuzcr/LIV_handhold] launch运行错误 (Issue #50)

***@***.***开源的

—
Reply to this email directly, view it on GitHub, or unsubscribe.
You are receiving this because you authored the thread.Message ID: ***@***.***&gt;
  Lianghongnan left a comment (xuankuzcr/LIV_handhold#50)

***@***.***开源的

—
Reply to this email directly, view it on GitHub, or unsubscribe.
You are receiving this because you authored the thread.Message ID: ***@***.***&gt;

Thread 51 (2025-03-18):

error when running mvs_camera_trigger.launch

jml-creator, 2025-03-18:
Thank you for sharing your code and expertise.

I am encountering an issue when trying to run `roslaunch mvs_ros_pkg mvs_camera_trigger.launch`. The following error is displayed:

`class_loader::LibraryUnloadException`

Could you kindly point me in the right direction to resolve this?

# parameters

1. hikrobot camera driver works fine

2. running from docker container

3. no error during build

4. rosdistro: noetic

5. opencv 4.2.0

6. stm32 trigger works fine

## error message

root@pl-NUC13ANKi5:/ros_ws# roslaunch mvs_ros_pkg mvs_camera_trigger.launch
... logging to /root/.ros/log/56f9fe00-031b-11f0-83df-e0c2643980a5/roslaunch-pl-NUC13ANKi5-1749.log
Checking log directory for disk usage. This may take a while.
Press Ctrl-C to interrupt
Done checking log file disk usage. Usage is <1GB.

started roslaunch server http://pl-NUC13ANKi5:37545/

SUMMARY
========

PARAMETERS
 * /rosdistro: noetic
 * /rosversion: 1.17.0

NODES
  /
    mvs_camera_trigger (mvs_ros_pkg/grabImgWithTrigger)
    rviz (rviz/rviz)

auto-starting new master
process[master]: started with pid [1757]
ROS_MASTER_URI=http://localhost:11311

setting /run_id to 56f9fe00-031b-11f0-83df-e0c2643980a5
process[rosout-1]: started with pid [1767]
started core service [/rosout]
process[mvs_camera_trigger-2]: started with pid [1770]
process[rviz-3]: started with pid [1775]
QStandardPaths: XDG_RUNTIME_DIR not set, defaulting to '/tmp/runtime-root'
MESA: warning: Driver does not support the 0xa7a0 PCI ID.
libGL error: failed to create dri screen
libGL error: failed to load driver: iris
MESA: warning: Driver does not support the 0xa7a0 PCI ID.
libGL error: failed to create dri screen
libGL error: failed to load driver: iris
[ INFO] [1742207641.325130219]: Successfully created handle for device 0
terminate called after throwing an instance of 'class_loader::LibraryUnloadException'
  what():  Attempt to unload library that class_loader is unaware of.
[mvs_camera_trigger-2] process has died [pid 1882, exit code -6, cmd /ros_ws/devel/lib/mvs_ros_pkg/grabImgWithTrigger /ros_ws/src/mvs_ros_pkg/config/left_camera_trigger.yaml __name:=mvs_camera_trigger __log:=/root/.ros/log/56f9fe00-031b-11f0-83df-e0c2643980a5/mvs_camera_trigger-2.log].
log file: /root/.ros/log/56f9fe00-031b-11f0-83df-e0c2643980a5/mvs_camera_trigger-2*.log
[mvs_camera_trigger-2] restarting process
process[mvs_camera_trigger-2]: started with pid [1905]
[ INFO] [1742207645.394004647]: Successfully created handle for device 0
^C[rviz-3] killing on exit
[mvs_camera_trigger-2] killing on exit

Harland666, 2025-03-27:
I also encountered the same problem. May I ask how you solved it?

jml-creator, 2025-03-28:
Harland666, I have not solve the issue yet. Looking forward to fix this.

Harland666, 2025-04-02:
Just make sure the parameters in MVS are set the same as those in the configuration file.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

Harland666, 2025-04-02:
Just make sure the parameters in MVS are set the same as those in the configuration file.

smallCuZ, 2025-04-03:
> Just make sure the parameters in MVS are set the same as those in the configuration file.

Thank you, the problem has been resolved！

Closed 2025-04-04.

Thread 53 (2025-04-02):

相机是否可以高频触发

sdwyc, 2025-04-02:
您好，首先感谢您的开源分享，我有一个疑问想请教您：如果我希望相机的数据频率能够保持到30hz，那么这样的话，我通过stm32发一个30hz的pwm触发相机，然后在ROS端，我手动分频，分为30hz和10hz两个相机频率进行发布，30hz的视频流用于其他应用，10hz的视频流用于跑LIVO算法，请问这样是可行的吗

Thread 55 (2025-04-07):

相机触发PWM相位的理解

zhSlamer, 2025-04-07:
请问为什么在定时器1Hz中断时，为什么对触发相机的定时器2相移50ms，TIM2->CNT=TIM2->ARR/2;
而不是 设置严格的脉冲上升沿一致
代码中相机的曝光时间为5000us = 5ms

感谢作者以及同学们帮助！

xuankuzcr, 2025-04-14:
@zhSlamer TIM2和TIM3设置的都是PWM2模式，PWM2计数器大于ARR/2是高电平，PWM1反之。为实现TIM2的上升沿与TIM3的1Hz中断严格同步，每次TIM3中断触发时，会强制将TIM2的计数器跳转到ARR/2位置，此时CNT立即大于CCR (50%占空比，CCR = ARR/2)，导致PWM输出瞬间变高，从而在TIM3的中断时刻生成一个精确对齐的上升沿。尽管此操作将TIM2的计数器设为半周期位置，但下一周期计数器仍会从0开始正常递增，确保TIM2的10Hz频率保持不变。（注：如果都是PWM1，TIM3中断里设置的应该是TIM2->CNT = 0）

这种强制相位重置，会消除累积的相位偏移，使得TIM2的每个上升沿始终与TIM3的中断事件严格对齐。

Closed 2025-04-25.

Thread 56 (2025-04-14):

运行mvs_camera_trigger.launch 无法捕获相机的图像

Victorrr1, 2025-04-14:
复现的时候使用的是海康MV-CU013-A0UC工业相机：
yaml文件配置如下：

%YAML:1.0
TopicName: "left_camera/image"

TriggerEnable: 0 # 0 stands for Off, 1 stands for On

ExposureAutoMode: 0 # 0 stands for Off, 1 stands for Once, 2 stands for Continues
ExposureTime: 80000 # us

image_scale: 1 # 1 0.5
GainAuto: 2 # Gain Auto, 0 stands for Off, 1 stands for Once, 2 stands for Continues
Gain: 15 # min: 0   max: 17.0166
Gamma: 0.7  # min: 0   max: 17.0166
GammaSelector: 1 # 0 stands for user, 1 stands for sRGB

PixelFormat: 3 # 0: RGB8, 1: BayerRG8, 2: BayerRG12Packed, 3: BayerGB12Packed

运行的时候：
MV_CC_ConvertPixelType failed! nRet [80000000], skipping this frame
SrcPixelType: 0x10c002c, Width: 1280, Height: 1024
SrcDataLen: 1966080, DstBufferSize: 1966080

海康SDK转换像素类型是失败，但是我查看了SDK的头文件输入类型和输出类型都是支持的 不知道是什么问题了。。

MiracleVae, 2025-04-14:
我也遇到了

xuankuzcr, 2025-04-14:
你俩相机型号都是多少

Victorrr1, 2025-04-14:
我用的是MV-CU013-A0UC

发自我的iPhone

------------------ 原始邮件 ------------------
发件人: Chunran Zheng ***@***.***&gt;
发送时间: 2025年4月14日 16:04
收件人: xuankuzcr/LIV_handhold ***@***.***&gt;
抄送: Luozhipeng0116 ***@***.***&gt;, Author ***@***.***&gt;
主题: Re: [xuankuzcr/LIV_handhold] 运行mvs_camera_trigger.launch 无法捕获相机的图像 (Issue #56)

你俩相机型号都是多少

—
Reply to this email directly, view it on GitHub, or unsubscribe.
You are receiving this because you authored the thread.Message ID: ***@***.***&gt;
  xuankuzcr left a comment (xuankuzcr/LIV_handhold#56)

你俩相机型号都是多少

—
Reply to this email directly, view it on GitHub, or unsubscribe.
You are receiving this because you authored the thread.Message ID: ***@***.***&gt;

MiracleVae, 2025-04-14:
我是CS060-10GC

xuankuzcr, 2025-04-14:
@Victorrr1 你相机支持 “Bayer GB 8/10/10Packed/12/12Packed“ 见 https://www.hikrobotics.com/cn/machinevision/productdetail/?id=12628
把PixelFormat设为3试试
https://github.com/xuankuzcr/LIV_handhold/blob/ae191786797f48d3672ab812fa896b8f06f17fd5/mvs_ros_driver/config/left_camera_trigger.yaml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

xuankuzcr, 2025-04-14:
@MiracleVae 你的相机支持BGR 8，见 https://www.hikrobotics.com/cn/machinevision/productdetail/?id=7482 具体运行报错是啥

xuankuzcr, 2025-04-14:
我明白了，上次添加多相机支持的时候有些地方没考虑Bayer格式，你把所有出现`stParam.nCurValue`的地方改成`stParam.nCurValue*3`试试@Victorrr1

Victorrr1, 2025-04-14:
这个我尝试了 好像不太行

不过我注意到我这个版本的海康MVS驱动MvCameraControl.h 中似乎没有MV_CC_ConvertPixelType的声明 里面有一个MV_CC_ConvertPixelTypeEx函数 我现在还在调试 不知道是不是这个的问题 如果我这边调试成功了 会更新这个issue

MiracleVae, 2025-04-14:
感谢您回复！
我的报错和那位相似，运行mvs_camera_trigger.launch时rviz中没有图像，终端不断报MV_CC_ConvertPixelType failed! nRet [80000000], skipping this frame.
配置文件中换了图像格式也是这样.

Victorrr1, 2025-04-14:
还是无法正常显示。。

MiracleVae, 2025-04-14:
按您的提示改了还是不行，报错没有变化，请问是否与MVS官方客户端的版本有关，我用官方客户端可以正常显示图像。

xuankuzcr, 2025-04-14:
要不加下我联系方式吧，Github主页有，一起看看问题 @MiracleVae @Victorrr1

AshadowZ, 2025-04-14:
我使用的是MV-CU013-A0UC，添加了BayerGB8的像素格式。然后按作者说的将所有出现stParam.nCurValue的地方改成stParam.nCurValue*3，就可以正常出图了。不然会报MV_E_BUFOVER的错误码，先缓存已满
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

Victorrr1, 2025-04-14:
好的@xuankuzcr  非常感谢郑博的指导

Victorrr1, 2025-04-14:
@AshadowZ 十分感谢您的回复！
根据您这个上面的错误码 我这个似乎是另一个问题 是错误或无效的句柄

MiracleVae, 2025-04-14:
@Victorrr1 你好，我这边可以看到图像了，你可以按我的方法试试。把MVS官方客户端降低版本，我原来是3.0.1，换成2.1.2，然后重新开一个终端source一下就可以了。这是2.1.2的链接https://download.csdn.net/download/qq_45445740/90146864?spm=1001.2014.3001.5501

Victorrr1, 2025-04-14:
好的 感谢您的分享 我马上尝试一下！

Victorrr1, 2025-04-14:
我来总结一下 出现MV_CC_ConvertPixelType failed 错误码80000000 需要把海康的驱动版本回退到2.1.2 这个时候运行代码会出现MV_CC_ConvertPixelType failed 错误码80000002 只需要按照

> 我明白了，上次添加多相机支持的时候有些地方没考虑Bayer格式，你把所有出现`stParam.nCurValue`的地方改成`stParam.nCurValue*3`试试，如果可以的话我更新上去，麻烦了 [@Victorrr1](https://github.com/Victorrr1)

将代码的buffer全部开成原来的三倍即可

Victorrr1, 2025-04-14:
非常感谢郑博的指导 也感谢 @MiracleVae @AshadowZ 两位老哥的指导 我马上把该issue关闭

Victorrr1, 2025-04-15:
@AshadowZ 你是对的 我昨天fast-livo2运行的时候发现libusb的动态库链接到海康的MVS中去了 修改了一下bashrc中动态库的顺序 发现运行相机驱动的时候又报错了，这次报了MV_CC_ConvertPixelType failed! nRet [80000006], skipping this frame（看样子它会随机报一个错？）

然后我重装了一下MVS，发现它会修改系统的bashrc并将自己lib的优先于系统的lib。 相机驱动能运行的关键是要用海康MVS的libusb库 然后fast-livo2运行的时候要隔离一下MVS的lib使用系统的libusb库即可。

quinnym233, 2025-07-29:
export LD_LIBRARY_PATH=/opt/MVS/lib/64:/opt/MVS/lib/32:/opt/MVS/lib/64:/opt/MVS/lib/32  指定库后还是报错[mvs_camera_trigger-1] restarting process
process[mvs_camera_trigger-1]: started with pid [15082]
/home/ym/fast_livo_ws/devel/lib/mvs_ros_driver/grabImgWithTrigger: error while loading shared libraries: libmessage_filters.so: cannot open shared object file: No such file or directory

xjy0410, 2025-09-01:
> export LD_LIBRARY_PATH=/opt/MVS/lib/64:/opt/MVS/lib/32:/opt/MVS/lib/64:/opt/MVS/lib/32 指定库后还是报错[mvs_camera_trigger-1] restarting process process[mvs_camera_trigger-1]: started with pid [15082] /home/ym/fast_livo_ws/devel/lib/mvs_ros_driver/grabImgWithTrigger: error while loading shared libraries: libmessage_filters.so: cannot open shared object file: No such file or directory

我也遇到了相同的问题，请问解决了吗？

Closed 2025-04-14.

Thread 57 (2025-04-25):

Female and Male  12-Pin Interface problem

KJ-Falloutlast, 2025-04-25:
郑博，你好，我最近用杜邦线测试AVIA 12孔接头的正负极，以保证我们的电压输出是正确的。这里有一个问题：
1. 我发现LVI-Handhold Readme中的公头和母头标反了，top应该是male，bottom应该是female，从机械结构的正视图来看，也是如此：公头顶上凹槽有一个封口，母头凹槽没有封口，望修正。PIN1对应的是电压正极，PIN2对应电压负级。以下是我测试的结果：

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

xuankuzcr, 2025-05-19:
感谢提醒，已修正

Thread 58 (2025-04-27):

[mvs_camera_trigger-1] process has died 问题记录

KJ-Falloutlast, 2025-04-27:
# 问题1： error when running mvs_camera_trigger.launch
通过GDB调试，发现段错误发生在 cv::FileStorage 构造函数，可能原因如下：
1. OpenCV 库版本冲突（高概率）
- 现象：cv::FileStorage 构造函数崩溃。
- 原因：ROS 的 cv_bridge 默认链接 OpenCV3，但是代码手动指定了 OpenCV4.2，导致运行时符号冲突。
- 验证方法：ldd devel/lib/mvs_ros_driver/grabImgWithTrigger | grep -E "opencv|cv_bridge"， 输出中同时出现 OpenCV3 和 OpenCV4 的库文件（如 libopencv_core.so.3.2 和 libopencv_core.so.4.2），所以可以确认存在版本冲突。

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

2. 参数文件路径错误（中概率）
- 现象：文件无法打开，但错误处理未正确触发。
- 原因：argv[1] 未正确传递参数文件路径，或文件权限不足。
- 验证方法：// 在 main() 中添加调试输出ROS_INFO_STREAM("Loading params from: " << params_file);struct stat buffer;if (stat(params_file.c_str(), &buffer) != 0) {ROS_ERROR("Params file does not exist!");exit(-1);}
解决方法：
1. 统一 OpenCV 版本（关键步骤）：将包括FAST_LIOV2，RPG，mv_ros_driver都必须采用Opencv 3的库，不要使用Opencv 4.2版本，否则会出现程序致命报错。

2.单独构造一个cpp文件测试cv::FileStroage问题: 通过测试，cmake中的OpenCV编译没问题，当修改成了OpenCV 4之后，运行代码，出现了process has died， 这表明该程序不能用OpenCV4版本运行，必须使用OpenCV 3版本运行
#include <opencv2/opencv.hpp>
#include <ros/ros.h>

int main(int argc, char** argv) {
    ros::init(argc, argv, "test_node");
    std::string params_file = argv[1];
    ROS_INFO("Opening file: %s", params_file.c_str());
    cv::FileStorage fs(params_file, cv::FileStorage::READ);
    if (fs.isOpened()) {
        ROS_INFO("File opened successfully");
    } else {
        ROS_ERROR("Failed to open file");
    }
    return 0;
}

## 问题2：对cv::Mat::Mat()未定义的引用
/home/cumt/hk_ws/FAST_LIVO2_WS/src/test/src/src/test_mat.cpp:14：对‘cv::Mat::Mat()’未定义的引用
解决方法：在cmake中，将find_package(Opencv REQUIRED)改成：
find_package(OpenCV 3.4 REQUIRED core highgui imgcodecs)

## 总结
1. mv_ros_driver不要使用Opencv 4，否则虽然能够成功编译，但是节点会死掉；
2. 未定义的引用部分，只需要在Opencv中增加core highgui imgcodecs即可。
最后附上mv_ros_driver的cmakelist, 希望对大家有帮助，给我点个赞，感谢郑博无私的贡献。
```cmake
cmake_minimum_required(VERSION 3.0.2)
project(mvs_ros_driver)
set(cv_bridge_DIR /usr/local/share/cv_bridge/cmake)

set(CMAKE_BUILD_TYPE "Debug")

add_compile_options(-std=c++14)

if(CMAKE_HOST_SYSTEM_PROCESSOR MATCHES "aarch64")
  LINK_DIRECTORIES(/opt/MVS/lib/aarch64/)
  message(STATUS "Running on arrch64")
elseif(CMAKE_HOST_SYSTEM_PROCESSOR MATCHES "x86_64")
  LINK_DIRECTORIES(/opt/MVS/lib/64/)
  message(STATUS "Running on x86_64")
endif()

find_package(catkin REQUIRED COMPONENTS
  cv_bridge
  image_transport
  roscpp
  rospy
  sensor_msgs
  std_msgs
  rosbag
)

find_package(OpenCV 3.4 REQUIRED core highgui imgcodecs)

find_package(PCL REQUIRED)

catkin_package(
 CATKIN_DEPENDS roscpp rospy std_msgs
)

include_directories(
  /opt/MVS/include
  ${catkin_INCLUDE_DIRS}
  ${OpenCV_INCLUDE_DIRS}
  ${PCL_INCLUDE_DIRS}
)

link_directories(
  ${catkin_LIB_DIRS}
)

add_executable(grabImgWithTrigger src/grab_trigger.cpp)

target_link_libraries(
  grabImgWithTrigger
  ${catkin_LIBRARIES}
  ${OpenCV_LIBS}
  MvCameraControl
)
```

chaoyue0925, 2025-05-16:
您好，想咨询一下如何处理opencv的版本冲突问题

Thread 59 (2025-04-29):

如果用真实的rtk来进行时间同步（也就是rtk、lidar、camera同步），整个同步方案应该怎么修改呢？

nowPB, 2025-04-29:

xuankuzcr, 2025-05-19:
https://github.com/hku-mars/FAST-LIVO2/issues/220

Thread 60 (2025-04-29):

关于无人机型号以及室内运行的可能性

steven2281, 2025-04-29:
郑博您好！非常感谢开源如此高质量的工作！这里想请教一下您使用的无人机和飞控系统的具体型号是什么？以及按照您的经验，如果想在略开阔的室内环境飞行无人机（比如博物馆，图书馆），理论上可行吗

xuankuzcr, 2025-05-19:
@steven2281 飞控用的PX4，无人机[见此](https://github.com/xuankuzcr/LIV_handhold/tree/main/drone_cad)；可行，狭窄的也可以飞，视频demo里面有展示

steven2281, 2025-05-19:
> [@steven2281](https://github.com/steven2281) 飞控用的PX4，无人机[见此](https://github.com/xuankuzcr/LIV_handhold/tree/main/drone_cad)；可行，狭窄的也可以飞，视频demo里面有展示

了解了，感谢郑博

Closed 2025-05-19.

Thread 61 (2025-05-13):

有没有在ros(noetic)系统中安装海康相机驱动的指导步骤

asurasoft, 2025-05-13:
官方需要安装哪几个包（https://www.hikrobotics.com/cn/machinevision/service/download/?module=0）
github这个仓库有什么关系（https://github.com/luckyluckydadada/HIKROBOT-MVS-CAMERA-ROS）

系统是ubuntu20.04（arm64）
catkin_make的时候报错

[100%] Linking CXX executable /home/orangepi/ws_hikrobot_camera/devel/lib/hikrobot_camera/hikrobot_camera
/usr/bin/ld: 找不到 -lGCBase_gcc421_v3_0
/usr/bin/ld: 找不到 -lMvCameraControl
/usr/bin/ld: 找不到 -lGenApi_gcc421_v3_0
/usr/bin/ld: 找不到 -lMVGigEVisionSDK
/usr/bin/ld: 找不到 -llog4cpp_gcc421_v3_0
/usr/bin/ld: 找不到 -lMVRender
/usr/bin/ld: 找不到 -lLog_gcc421_v3_0
/usr/bin/ld: 找不到 -lMvUsb3vTL
/usr/bin/ld: 找不到 -lMathParser_gcc421_v3_0
/usr/bin/ld: 找不到 -lNodeMapData_gcc421_v3_0
/usr/bin/ld: 找不到 -lMediaProcess
/usr/bin/ld: 找不到 -lXmlParser_gcc421_v3_0
collect2: error: ld returned 1 exit status
make[2]: *** [hikrobot_camera/CMakeFiles/hikrobot_camera.dir/build.make:204：/home/orangepi/ws_hikrobot_camera/devel/lib/hikrobot_camera/hikrobot_camera] 错误 1
make[1]: *** [CMakeFiles/Makefile2:995：hikrobot_camera/CMakeFiles/hikrobot_camera.dir/all] 错误 2
make: *** [Makefile:141：all] 错误 2
Invoking "make -j8 -l8" failed

xuankuzcr, 2025-05-19:
详细见此仓库readme; 和他没有关系

asurasoft, 2025-05-22:
谢谢，我尝试了，安装成功。
orangepi 5 plus + focal（xfce)
先安装mvs的sdk，然后安装mvs_ros_pkg，发现可以在报错的情况下继续运行
如果使用mvs_ros_driver，需要直接进终端，方可不报错启动

Closed 2025-05-22.

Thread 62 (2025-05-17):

MV-CA013-21UC停产

MaxSingularity, 2025-05-17:
[MV-CA013-21UC]这款相机已经停产了，麻烦问一下，有平替的相机吗？
可以快速正常运行FAST-LIVO
谢谢

xuankuzcr, 2025-05-19:
全局曝光的都行，可以在[这里](https://www.hikrobotics.com/cn/machinevision/visionproduct?id=283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)找，普惠型工业相机如MV-CU004-10GC，MV-CU013-A0UC等等

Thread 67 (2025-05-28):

您好，有两个问题请教一下。1、在海康相机客户端设置 采集频率为10HZ，然后运行相机ros驱动后采集频率为6HZ，这是什么原因。2、相机雷达采用硬同步UTC时间是2020年吗？现在需要将相机雷达和大疆M350的rtk真值采集到一个数据包中，但是用evo评估的时候真值轨迹和fast_livo2轨迹相差很大

dupeihua09, 2025-05-28:

xuankuzcr, 2025-06-09:
1、见Jcs0213的回复
2、是
3、轨迹评估，需要先补偿外参后再做ICP对齐，参考[这个](https://github.com/hku-mars/FAST-LIVO2/tree/main/Log/result/ntu_viral)

dupeihua09, 2025-06-12:
非常感谢，请问这个Jcs0213的回复是什么

> 1、见Jcs0213的回复 2、是 3、轨迹评估，需要先补偿外参后再做ICP对齐，参考[这个](https://github.com/hku-mars/FAST-LIVO2/tree/main/Log/result/ntu_viral)

Jcs0213, 2025-06-12:
> 非常感谢，请问这个Jcs0213的回复是什么
>
> > 1、见Jcs0213的回复 2、是 3、轨迹评估，需要先补偿外参后再做ICP对齐，参考[这个](https://github.com/hku-mars/FAST-LIVO2/tree/main/Log/result/ntu_viral)

就是我的回复，检查数据的带宽以及传输接口的带宽

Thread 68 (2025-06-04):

Hex file for STM32

theanhnguyen3112, 2025-06-04:
Thank you for this repo, it helps me a lot. thank you, if you can give me the .hex file of stm32 it would be great

Yccmv, 2025-07-06:
I haven't tried it for this project, so no guarantees, but here's how I'd probably do it:

1. Get STM32CubeIDE and an ST-LINK programmer.
2. Create a new STM32 project for the STM32F103C8T6.
3. Copy all the .c and .h files from the stm32_timersync-open/USER folder into your project's Core/Src. Just overwrite the existing main.c.
4. Try to build it (hit the hammer icon).
5. If it compiles, the .hex file should be in the Debug folder.
6. Flash it to the board with the ST-LINK.

let me know if it works!

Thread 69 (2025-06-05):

jetson origin agx arm64架构打开livoxiewer2时显示如下格式错误

luliang520, 2025-06-05:
您好，想请教一下，jetson origin agx arm64架构打开livoxiewer2时显示如下格式错误，是这一款livox客户端不支持arm64架构嘛？
nvidia@EAORA07B:~/Downloads/LivoxViewer2 for Ubuntu v2.3.0$ ./LivoxViewer2.bash
./LivoxViewer2.bash: 5: /home/nvidia/Downloads/LivoxViewer2 for Ubuntu v2.3.0/LivoxViewer2/Binaries/Linux/LivoxViewer2: Exec format error

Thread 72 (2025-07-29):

roslaunch mvs_ros_driver mvs_camera_trigger.launch驱动报错

quinnym233, 2025-07-29:
~/fast_livo_ws$ roslaunch mvs_ros_driver mvs_camera_trigger.launch
... logging to /home/ym/.ros/log/3172c978-6c3e-11f0-a586-659f49a864b4/roslaunch-ym-Legion-Y7000P-IRH8-16276.log
Checking log directory for disk usage. This may take a while.
Press Ctrl-C to interrupt
Done checking log file disk usage. Usage is <1GB.

started roslaunch server http://ym-Legion-Y7000P-IRH8:43987/

SUMMARY
========

PARAMETERS
 * /rosdistro: noetic
 * /rosversion: 1.17.4

NODES
  /
    mvs_camera_trigger (mvs_ros_driver/grabImgWithTrigger)
    rviz (rviz/rviz)

ROS_MASTER_URI=http://localhost:11311

process[mvs_camera_trigger-1]: started with pid [16290]
process[rviz-2]: started with pid [16291]
[device 0]:
Device Model Name: MV-CU013-A0UC
SerialNumber: DA6782930
terminate called after throwing an instance of 'class_loader::LibraryUnloadException'
  what():  Attempt to unload library that class_loader is unaware of: /opt/ros/noetic/lib//libcompressed_depth_image_transport.so
[mvs_camera_trigger-1] process has died [pid 16290, exit code -6, cmd /home/ym/fast_livo_ws/devel/lib/mvs_ros_driver/grabImgWithTrigger /home/ym/fast_livo_ws/src/mvs_ros_driver/config/left_camera_trigger.yaml __name:=mvs_camera_trigger __log:=/home/ym/.ros/log/3172c978-6c3e-11f0-a586-659f49a864b4/mvs_camera_trigger-1.log].
log file: /home/ym/.ros/log/3172c978-6c3e-11f0-a586-659f49a864b4/mvs_camera_trigger-1*.log
报错，export LD_LIBRARY_PATH=/opt/MVS/lib/64:/opt/MVS/lib/32:/opt/MVS/lib/64:/opt/MVS/lib/32指定库后报错变为：
roslaunch mvs_ros_driver mvs_camera_trigger.launch
... logging to /home/ym/.ros/log/3172c978-6c3e-11f0-a586-659f49a864b4/roslaunch-ym-Legion-Y7000P-IRH8-16526.log
Checking log directory for disk usage. This may take a while.
Press Ctrl-C to interrupt
Done checking log file disk usage. Usage is <1GB.

started roslaunch server http://ym-Legion-Y7000P-IRH8:39119/

SUMMARY
========

PARAMETERS
 * /rosdistro: noetic
 * /rosversion: 1.17.4

NODES
  /
    mvs_camera_trigger (mvs_ros_driver/grabImgWithTrigger)
    rviz (rviz/rviz)

ROS_MASTER_URI=http://localhost:11311

process[mvs_camera_trigger-1]: started with pid [16541]
/home/ym/fast_livo_ws/devel/lib/mvs_ros_driver/grabImgWithTrigger: error while loading shared libraries: libmessage_filters.so: cannot open shared object file: No such file or directory
/opt/ros/noetic/lib/rviz/rviz: error while loading shared libraries: librviz.so: cannot open shared object file: No such file or directory
failed to start local process: /opt/ros/noetic/lib/rviz/rviz -d /home/ym/fast_livo_ws/src/mvs_ros_driver/rviz_cfg/mvs_camera.rviz __name:=rviz __log:=/home/ym/.ros/log/3172c978-6c3e-11f0-a586-659f49a864b4/rviz-2.log
local launch of rviz/rviz failed

sakakiaaa, 2025-08-11:
感谢指导！

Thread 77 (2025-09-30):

请问我这边相机数据会出现相邻两帧时间戳相同的情况，但是雷达此时的时间戳是正常的，这个是什么原因呢？谢谢~

dandelion-chu, 2025-09-30:
我这边使用最新的代码烧写进32板，并在mid360和海康相机上进行了测试，流程已正常走通，且可以收到数据包和同步的时间戳，但是发现会出现相机偶尔有相邻两帧时间戳完全相同的情况，此时雷达这个时间戳是正常的，感觉像是timeshare没有更新一样，请问您遇到过这个情况吗？会是什么原因导致的呢？截图如下：

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

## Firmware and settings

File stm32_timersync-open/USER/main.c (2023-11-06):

#include "led.h"
#include "delay.h"
#include "key.h"
#include "sys.h"
#include "usart.h"
#include "timer.h"
//灰色 SWIO  7 左4
//白色 SWCLK 9 左5
//黑色 GND 右 2


extern vu16 var_Exp;
int main(void)
{

	delay_init();	    	 //延时函数初始化	  
	NVIC_PriorityGroupConfig(NVIC_PriorityGroup_2); 	 //设置NVIC中断分组2:2位抢占优先级，2位响应优先级
	//uart_init(115200);	 //串口初始化为115200
	uart_init(9600);
 	LED_Init();			     //LED端口初始化
	//1000 ms 50 
	TIM2_PWM_Init(999,7199); // 10 Hz    pin_A1       

 	TIM3_PWM_Init(9999,7199);	 // 1 Hz  pin_B5


	
	while(1)
	{
		
	}
}

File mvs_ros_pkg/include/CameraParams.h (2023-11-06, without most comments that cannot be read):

#ifndef _MV_CAMERA_PARAMS_H_
#define _MV_CAMERA_PARAMS_H_

#include "PixelType.h"

#ifndef __cplusplus
typedef char bool;
#define true 1
#define false 0
#endif


#define MV_UNKNOW_DEVICE                                                       \
  0x00000000
#define MV_GIGE_DEVICE 0x00000001
#define MV_1394_DEVICE 0x00000002
#define MV_USB_DEVICE 0x00000004
#define MV_CAMERALINK_DEVICE                                                   \
  0x00000008

typedef struct _MV_GIGE_DEVICE_INFO_ {
  unsigned int nIpCfgOption;
  unsigned int
      nIpCfgCurrent;       // IP configuration:bit31-static bit30-dhcp bit29-lla
  unsigned int nCurrentIp; // curtent  | en:
  unsigned int nCurrentSubNetMask; // curtent subnet mask
  unsigned int nDefultGateWay;     // current gateway | en
  unsigned char chManufacturerName[32];
  unsigned char chModelName[32];
  unsigned char chDeviceVersion[32];
  unsigned char chManufacturerSpecificInfo[48];
  unsigned char chSerialNumber[16];
  unsigned char chUserDefinedName[16];

  unsigned int nNetExport;

  unsigned int nReserved[4];

} MV_GIGE_DEVICE_INFO;

#define INFO_MAX_BUFFER_SIZE 64
typedef struct _MV_USB3_DEVICE_INFO_ {
  unsigned char CrtlInEndPoint;
  unsigned char CrtlOutEndPoint;
  unsigned char StreamEndPoint;
  unsigned char EventEndPoint;
  unsigned short idVendor;
  unsigned short idProduct;
  unsigned int nDeviceNumber;
  unsigned char chDeviceGUID[INFO_MAX_BUFFER_SIZE];
                                                    // GUID Number
  unsigned char
      chVendorName[INFO_MAX_BUFFER_SIZE];
  unsigned char chModelName[INFO_MAX_BUFFER_SIZE];
  unsigned char
      chFamilyName[INFO_MAX_BUFFER_SIZE];
  unsigned char
      chDeviceVersion[INFO_MAX_BUFFER_SIZE];
  unsigned char chManufacturerName[INFO_MAX_BUFFER_SIZE];
                                                          // en:Manufacturer
                                                          // Name
  unsigned char
      chSerialNumber[INFO_MAX_BUFFER_SIZE];
  unsigned char chUserDefinedName[INFO_MAX_BUFFER_SIZE];
                                                         // en:User Defined Name
  unsigned int nbcdUSB;
  unsigned int nReserved[3];
} MV_USB3_DEVICE_INFO;

typedef struct _MV_CamL_DEV_INFO_ {
  unsigned char chPortID[INFO_MAX_BUFFER_SIZE];
  unsigned char chModelName[INFO_MAX_BUFFER_SIZE];
  unsigned char chFamilyName[INFO_MAX_BUFFER_SIZE];
  unsigned char chDeviceVersion[INFO_MAX_BUFFER_SIZE];
  unsigned char chManufacturerName[INFO_MAX_BUFFER_SIZE];
  unsigned char chSerialNumber[INFO_MAX_BUFFER_SIZE];
  unsigned int nReserved[38];
} MV_CamL_DEV_INFO;


typedef struct _MV_CC_DEVICE_INFO_ {
  // ch:common info | en:common info
  unsigned short nMajorVer;
  unsigned short nMinorVer;
  unsigned int nMacAddrHigh;
  unsigned int nMacAddrLow;

  unsigned int nTLayerType;
                            // Transport Layer Protocol Type, e.g.
                            // MV_GIGE_DEVICE

  unsigned int nReserved[4];

  union {
    MV_GIGE_DEVICE_INFO stGigEInfo;
    MV_USB3_DEVICE_INFO stUsb3VInfo;
    MV_CamL_DEV_INFO stCamLInfo;
    // more ...
  } SpecialInfo;

} MV_CC_DEVICE_INFO;


typedef struct _MV_NETTRANS_INFO_ {
  int64_t nReviceDataSize;

                           // en:Received Data Size  [Calculate the Data Size
                           // between StartGrabbing and StopGrabbing]
  int nThrowFrameCount;
  unsigned int nNetRecvFrameCount;
  int64_t nRequestResendPacketCount;
  int64_t nResendPacketCount;

} MV_NETTRANS_INFO;


// instances
#define MV_MAX_TLS_NUM 8

#define MV_MAX_DEVICE_NUM 256


typedef struct _MV_CC_DEVICE_INFO_LIST_ {
  unsigned int nDeviceNum;
  MV_CC_DEVICE_INFO *pDeviceInfo[MV_MAX_DEVICE_NUM];
                                                     // en:Support up to 256
                                                     // devices

} MV_CC_DEVICE_INFO_LIST;


typedef struct _MV_FRAME_OUT_INFO_ {
  unsigned short nWidth;
  unsigned short nHeight;
  enum MvGvspPixelType enPixelType;

  unsigned int nFrameNum;
  unsigned int nDevTimeStampHigh;
  unsigned int nDevTimeStampLow;
  unsigned int nReserved0;
  int64_t nHostTimeStamp;

  unsigned int nFrameLen;

  unsigned int nLostPacket;
  unsigned int nReserved[2];
} MV_FRAME_OUT_INFO;


typedef struct _MV_CHUNK_DATA_CONTENT_ {
  unsigned char *pChunkData;
  unsigned int nChunkID;
  unsigned int nChunkLen;

  unsigned int nReserved[8];

} MV_CHUNK_DATA_CONTENT;
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

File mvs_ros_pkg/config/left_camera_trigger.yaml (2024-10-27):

%YAML:1.0

#--------------------------------------------------------------------------------------------
# Camera Parameters. Adjust them!
#--------------------------------------------------------------------------------------------
# SerialNumber: "00G66398256"
TopicName: "left_camera/image"

TriggerEnable: 1 # 0 stands for Off, 1 stands for On

ExposureAutoMode: 0 # 0 stands for Off, 1 stands for Once, 2 stands for Continues
ExposureTime: 5000 # us

# ExposureAutoMode: 2
# AutoExposureTimeLower: 100
# AutoExposureTimeUpper: 20000

image_scale: 0.5 # 1 0.5
GainAuto: 2 # Gain Auto, 0 stands for Off, 1 stands for Once, 2 stands for Continues
Gain: 15 # min: 0   max: 17.0166
Gamma: 0.7  # min: 0   max: 17.0166
GammaSelector: 1 # 0 stands for user, 1 stands for sRGB
# GammaEnable: 1

PixelFormat: 0 # 0: RGB8, 1: BayerRG8, 2: BayerRG12Packed, 3: BayerGB12Packed

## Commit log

2023-11-30 [Add] Add some pics and videos.
    [AVIA.SLDASM, DJI_manifold2.SLDPRT, FL2-020-R0.SLDPRT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]
2023-11-30 [Update] update material table, gif and discription.
2024-01-20 upload MVS driver for camera
2024-05-27 [fix] fix GPRMC time and checksum generation, electronic connection, and material list.
    [AVIA.SLDASM, DJI_manifold2.SLDPRT, FL2-020-R0.SLDPRT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]
2024-07-14 [Fix] fix the memory init & imu timestamp compensate bug.
2024-07-15 [Fix] fix the bug in mvs_ros_driver and livox_ros_driver.
    [lds_lidar.cpp, main.c]
2024-07-16 [Add] add STM32 and RS485 electronic connection.
    [Add] add STM32 and RS485 electronic connection.
    Update README.md
2024-07-21 [Fix] fix the dependency on the shared timestamp path.
    [left_camera_trigger.yaml]
2024-09-11 [Add] add STM32 PA9 (TXD) pin description.
2024-10-03 [Fix] fix the camera driver and add aarch64 support.
    [left_camera_trigger.yaml]
2024-10-31 [Fix] fix GPRMC timestamp mismatch with LiDAR msg (month and day).
    [timesync.cpp]
